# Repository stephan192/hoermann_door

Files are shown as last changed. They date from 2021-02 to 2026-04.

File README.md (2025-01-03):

# hoermann_door
Control Hörmann doors drives directly via MQTT from Home Assistant

Inspired by https://blog.bouni.de/posts/2018/hoerrmann-uap1/

**USE AT YOUR OWN RISK!**

# Overview

This repo contains the pcb files as well as the software to build an interface device which connects Hörmann door drives like the Supramatic E3 to Home Assistant. The interface device emulates an UAP1 to interact with the door drive. Additionally a BME280 can be connected via I2C to measure temperature, humidity and pressure.

<p align="center">
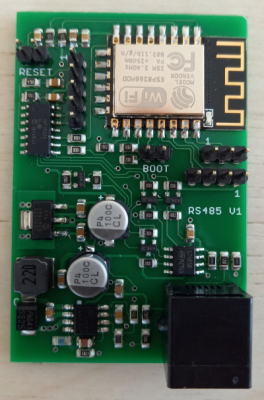
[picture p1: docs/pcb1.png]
    
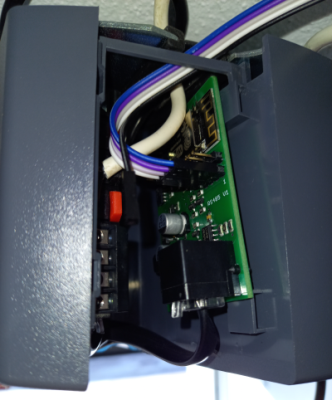
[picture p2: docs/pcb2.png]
    
</p>

The door drive is automatically added to Home Assistant via [MQTT Discovery](https://www.home-assistant.io/docs/mqtt/discovery/).

<p align="center">
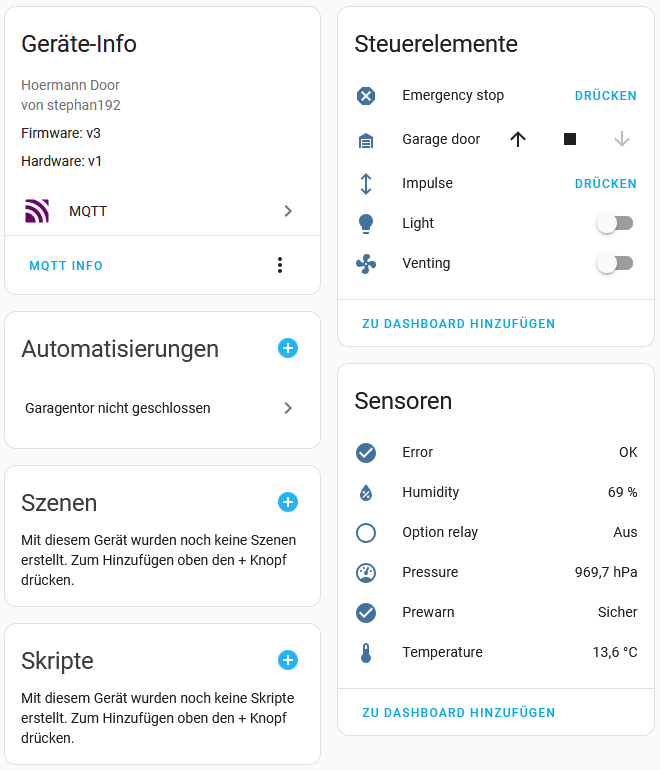
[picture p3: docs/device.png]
    
</p>

# Folder structure

* `board`: The Eagle schematic and board files
* `docs`: Documentation
* `esp8266`: Arduino project. Communication to Home Assistant via wifi and mqtt
* `pic16`: MPLabX project. Communication with door drive via Hörmann bus

# Thing to do first

1. Get a pcb
    * Optionally, get BME280 sensor pcb
    * Supply pcb with 24V via pins 2 & 3 of `J1`
    * Check if 5V and 3.3V are fine
1. Get tools listed below
1. Rename esp8266/config_template.h to esp8266/config.h and adjust to your environment
1. Add `esp8266` boards to Arduino IDE
    * Open Preferences window
    * Enter http://arduino.esp8266.com/stable/package_esp8266com_index.json into Additional Board Manager URLs field. You can add multiple URLs, separating them with commas.
    * Open Boards Manager from Tools > Board menu and find `esp8266` platform.
    * Click install button.
    * Select `NodeMCU 1.0 (ESP-12E Module)` as board
1. Add Libraries to Arduino IDE
    * Open Sketch > Include library -> Manage libraries...
    * Install `PubSubClient` (tested with version 2.8.0)
    * Install `PubSubClientTools` (tested with version 0.6.0)
    * Install `Adafruit Unified Sensor` (tested with version 1.1.4)
    * Install `Adafruit BME280 Library` (tested with version 2.1.2)
1. First flashing of `esp8266`
    * Get a cheap USB-UART converter (like the ones with a `CP210x`)
    * Connect the converter to `SV3` (RX, TX and GND)
    * Short `JP1` (Boot mode)
    * Power up board. If board was powered before reset `esp8266` by shorting `JP2`(Reset) for a short time
1. Flashing `pic16`
    * Get a Microchip programmer which supports the pic16 (PICkit3, ICD3, ...)
    * Connect the programmer to `SV1`
    * Open MPLabX and click on File -> Open Project
    * Select `pic16` subfolder (chip icon)
    * Click Clean an Build Main Project
    * Click Make and Program Device Main Project

# Used tools

## Schematic and board
* Eagle 7.2.0

## ESP8266
* Arduino IDE 1.8.13
* USB-UART converter

## PIC16
* MPLabX v5.45
* Device Family Pack PIC16F1xxxx_DFP 1.5.133
* XC8 v2.32
* PICkit3

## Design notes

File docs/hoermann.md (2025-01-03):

# Connector pinning 
1. ???
2. 24VDC
3. GND
4. ???
5. RS485, DATA-
6. RS485, DATA+

# Communication basics
* RS485 communication
* 19200Baud
* 8 databits
* No parity
* 1 Stop bit

# Typical message flow

## Startup
After Powerup the master sends the **Broadcast status** and the **Slave scan** messages alternating. The slave address used for the **Slave scan** is decremented each time a new message is send. The repeatedly used slave address range is `0x90` down to `0x10`.

## Slave detection
If a slave answers to its **Slave scan** message with **Slave scan response** the master detects the slave an starts asking the slave with **Slave status request** messages.

## Normal operation
The master sends the **Broadcast status** and the **Slave status request** messages alternating. The slave has to respond with **Slave status response**. If the slave doesn't respond the master will show error **7** and the door will not move anymore.

# Messages

## Message structure
| 0 | 1 | 2 | 3  | | length+2 | length+3 |
|---|---|---|----|-----|---|---|
| Sync break | address | counter+length | d0 | ... | dn | crc |

* `counter` are the upper 4 bits of byte 2. The slave has to answer with `cnt+1` when he received `cnt` as counter from the master.
* `length` are the lower 4 bits of byte 2. Length is the number of data bytes `d0`up to `dn`.

## CRC calculation
* 8 bit CRC
* Polynomial: `0x07`
* Initial value: `0xF3`
* The CRC is calculated over all bytes starting with the address byte and ending with the last data byte

## Known addresses
* `0x00`: Broadcast
* `0x80`: Master (door drive)
* `0x28`: UAP1

## Known commands
* `0x01`: Slave scan
* `0x20`: Slave status request
* `0x29`: Slave status response

## Known messages

### Broadcast status
Sender : Master

| 0 | 1 | 2 | 3  | 4  | 5 |
|---|---|----- |----|----|-----|
| Sync break | Broadcast addr | 0x?2 | d0 | d1 | crc |

* d0 bits:
    * `0`: door open
    * `1`: door closed
    * `2`: optional/external relay (relay 03 on UAP1)
    * `3`: light relay
    * `4`: error active
    * `5`: direction when moving (=1 closing, =0 opening)
    * `6`: door is moving
    * `7`: door is in venting position (**H** on display)
* d1 bits:
    * `0`: pre-warning active
    * `1`: ??? (seems to be always 1)
    * `2`: ???
    * `3`: ???
    * `4`: ???
    * `5`: ???
    * `6`: ???
    * `7`: ???

### Slave scan
Sender: Master

| 0 | 1 | 2 | 3 | 4 | 5 |
|---|---|----- |-----|---|-----|
| Sync break | Slave addr | 0x?2 | cmd | sender | crc |

* cmd = `0x01`: Slave scan
* sender = `0x80`: Master address

### Slave scan response
Sender: Slave

| 0 | 1 | 2 | 3 | 4 | 5 |
|---|---|----- |---|---|-----|
| Sync break | Master addr | 0x?2 | type | addr | crc |

* type = `0x14`: UAP1 type
* addr = `0x28`: UAP1 address

### Slave status request
Sender: Master

| 0 | 1 | 2 | 3 | 4 |
|---|---|----- |-----|-----|
| Sync break | Slave addr | 0x?1 | cmd | crc |

* cmd = `0x20`: Slave status request

### Slave status response
Sender: Slave

| 0 | 1 | 2 | 3 | 4  | 5  | 6 |
|---|---|----- |-----|----|----|-----|
| Sync break | Master addr | 0x?3 | cmd | d0 | d1 | crc |

* cmd = `0x29`: Slave status response
* d0 bits:
    * `0`: Trigger open door
    * `1`: Trigger close door
    * `2`: Trigger impulse (stop if door is moving, reverse direction if stopped, behaviour like the button on the remote control)
    * `3`: Toggle light relais
    * `4`: Trigger venting position
    * `5`: ???
    * `6`: ???
    * `7`: ???
* d1 bits:
    * `0`: ???
    * `1`: ???
    * `2`: ???
    * `3`: ???
    * `4`: State of pin `S0` on UAP1, i.e. the emergency cut-off button (normally `1`; if this bit is set to `0` the drive stops and error **4** is shown on the display)
    * `5`: ???
    * `6`: ???
    * `7`: ???

## Examples

### Broadcast status
| 0  | 1 | 2 | 3 | 4 | 5 |
|----|---|---|---|---|---|
| | 0x00 | 0x52 | 0x01 | 0x02 | 0xD0 |

* `0x00`: Broadcast
* `0x52`: ((0x52 & 0xF0) >> 4) = 5 = counter , (0x52 & 0x0F) = 2 = length
* `0x01`: d0, door open
* `0x02`: d1, ???
* `0xD0`: CRC

### Slave status response
| 0  | 1 | 2 | 3 | 4 | 5 | 6 |
|----|---|---|---|---|---|---|
| | 0x80 | 0x63 | 0x29 | 0x01 | 0x10 | 0x4B |

* `0x80`: Master
* `0x63`: ((0x63 & 0xF0) >> 4) = 6 = counter , (0x63 & 0x0F) = 3 = length
* `0x29`: Slave status response 
* `0x01`: d0, trigger door open
* `0x10`: d1, no emergency cut-off
* `0x4B`: CRC

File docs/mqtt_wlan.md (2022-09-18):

# Configuration
The configuration is stored in `esp8266\config.h`. If file doesn't exist copy `esp8266\config_template.h` and adopt to your needs.

# Basics
| Define | Description |
|---|---|
| `HOSTNAME` | Hostname used for WIFI, OTA and MQTT |
| `WIFI_SSID` | WIFI ssid to which the ESP should connect |
| `WIFI_PASS` | WIFI password used to connect to `WIFI_SSID` |
| `MQTT_SERVER` | IP of the MQTT server to which the ESP should connect |
| `MQTT_PORT` | Port of the MQTT server to which the ESP should connect (typically 1883) |
| `MQTT_USER` | Username used to connect to the MQTT server |
| `MQTT_PASSWORD` | Password used to connect to the MQTT server |
| `OTA_PASSWORT`  | Password used for over the air updates from Arduino IDE |
| `BME280_I2C_ADR`| I2C address of the BME280 |

# MQTT
| Define | Description |
|---|---|
| `STATE_TOPIC` | MQTT topic to which the current state of the door is published (content type: `string`, possible values: `open`, `closed`, `venting`, `opening`, `closing`, `error`, `stopped`) |
| `SET_TOPIC` | Subscribed MQTT topic to retrieve commands (content type: `string`, possible values: `OPEN`, `CLOSE`, `STOP`, `VENTING`, `TOGGLE_LIGHT`) |
| `BME280_VALUE_TOPIC` | MQTT topic to which the current value of the BME280 is published (content type: `JSON string`, example: `{ "temperature_C" : 8.24, "humidity" : 66.26, "pressure_hPa" : 986.41 }`) |
| `BME280_STATE_TOPIC` | MQTT topic to which the current state of the BME280 is published (content type: `string`, possible values: `online`, `offline`) |

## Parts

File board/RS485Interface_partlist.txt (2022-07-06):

Partlist

Exported from RS485Interface.sch at 06.07.2022 19:41:02

EAGLE Version 7.2.0 Copyright (c) 1988-2014 CadSoft

Assembly variant: 

Part     Value             Device            Package      Library                Sheet

C1       10u               C-EUC0805         C0805        rcl                    1
C2       10n               C-EUC0805         C0805        rcl                    1
C3       33p               C-EUC0805         C0805        rcl                    1
C4       100n              C-EUC0805         C0805        rcl                    1
C5       10n               C-EUC0805         C0805        rcl                    1
C6       100n              C-EUC0805         C0805        rcl                    1
C7       10u               C-EUC0805         C0805        rcl                    1
C8       100n              C-EUC0805         C0805        rcl                    1
C9       100n              C-EUC0805         C0805        rcl                    1
C10      10u               C-EUC0805         C0805        rcl                    1
C11      10u               C-EUC0805         C0805        rcl                    1
C12      100n              C-EUC0805         C0805        rcl                    1
C13      100u              UCL               UCL6.3       RS485Interface         1
C14      100u              UCL               UCL6.3       RS485Interface         1
C15      10u               C-EUC0805         C0805        rcl                    1
D1       SS25              SS25              DO-214AA     RS485Interface         1
IC1      PIC16F15324-I/SL  PIC16F15324-I/SL  SOIC14       RS485Interface         1
IC2      AOZ1283PI         AOZ1283PI         SO8+PAD      RS485Interface         1
IC3      MCP1826S-3302E/DB MCP1826S-3302E/DB SOT-223-3    RS485Interface         1
IC4      ST485BDR          ST485BDR          SOIC8        RS485Interface         1
J1       615006138421      615006138421      615006138421 InputOutputIO (rev19b) 1
JP1                        JP1E              JP1          jumper                 1
JP2                        JP1E              JP1          jumper                 1
L1       SRN6045TA-220M    SRN6045TA-220M    SRN6045TA    RS485Interface         1
R1       200k              R-EU_R0805        R0805        rcl                    1
R2       10k               R-EU_R0805        R0805        rcl                    1
R3       470R              R-EU_R0805        R0805        rcl                    1
R4       20k               R-EU_R0805        R0805        rcl                    1
R5       120R              R-EU_R0805        R0805        rcl                    1
R6       20k               R-EU_R0805        R0805        rcl                    1
R7       10k               R-EU_R0805        R0805        rcl                    1
R8       10k               R-EU_R0805        R0805        rcl                    1
R9       10k               R-EU_R0805        R0805        rcl                    1
R10      10k               R-EU_R0805        R0805        rcl                    1
R11      10k               R-EU_R0805        R0805        rcl                    1
R12      10k               R-EU_R0805        R0805        rcl                    1
R13      10k               R-EU_R0805        R0805        rcl                    1
R14      10k               R-EU_R0805        R0805        rcl                    1
R15      100R              R-EU_R0805        R0805        rcl                    1
R16      100R              R-EU_R0805        R0805        rcl                    1
R17      10k               R-EU_R0805        R0805        rcl                    1
R18      10k               R-EU_R0805        R0805        rcl                    1
R19      10k               R-EU_R0805        R0805        rcl                    1
R20      10k               R-EU_R0805        R0805        rcl                    1
R21      10k               R-EU_R0805        R0805        rcl                    1
R22      12k               R-EU_R0805        R0805        rcl                    1
R23      10k               R-EU_R0805        R0805        rcl                    1
R24      68k               R-EU_R0805        R0805        rcl                    1
R25      43k               R-EU_R0805        R0805        rcl                    1
R26      8k2               R-EU_R0805        R0805        rcl                    1
SV1                        MA05-1            MA05-1       con-lstb               1
SV2                        MA04-1            MA04-1       con-lstb               1
SV3                        MA03-1            MA03-1       con-lstb               1
T1       BSS138            BSS138            SOT-23       RS485Interface         1
T2       BSS138            BSS138            SOT-23       RS485Interface         1
T3       BSS138            BSS138            SOT-23       RS485Interface         1
T4       BSS138            BSS138            SOT-23       RS485Interface         1
U1       ESP-12F           ESP12ESMD         ESP12E-SMD   esp8266modules         1

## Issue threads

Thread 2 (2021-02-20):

PCB source

riogrande75, 2021-02-20:
I've been interrested for a while already in hoermann-hcp protocol, but this seems to be the most closest and finished project to fit my needs.
Is there a source where I can get this pcb boards?

stephan192, 2021-02-21:
Currently there is no source.
But if more people are interested i can setup one.

stephan192, 2021-03-03:
I don't know a source where to get the PCBs and i will not setup one.

stephan192, 2021-03-17:
I added gerber files to the repository but i'm not 100% sure if they are working.
I ordered my empty PCBs also at JLCPCB (without assembly) back in 2019 and i think i used the added gerber files but i'm not 100% sure.

@jmonsted if you plan to order boards can please give feedback if the gerber files are fine or not?

jmonsted, 2021-03-18:
Thanks Stephan. I found out that EasyEDA would load .sch and .brd files and already ordered that way. JLCPCB claims it's already manufactured :)
Time to source the parts...

JPM87, 2021-04-25:
Hi Stephan, thanks for sharing. I am not familiar with microcontrollers so can we replace the PIC16F15324 with PIC16F1503?

thomasdupas, 2021-04-26:
Very nice Stephan, even though I found this project way too late (I have an UAP1, with a 8266 interfaced with it on dev board; but instead of creating a PCB to do it properly I might as well use this PCB/project and eliminate the middle man)

@jmonsted since we're ~1 month further, did you succeed to source the parts? I was going over the BOM trying to match components, but not certain about some (for example SRN6045TA-, doesn't contain a value, but looking at the PCB picture it might be a SRN6045TA-220M due to the 220 print?), so I'd like to cross-reference if you're willing to share.

stephan192, 2021-04-28:
You're right L1 is a SRN6045TA-220M.
See https://github.com/stephan192/hoermann_door/blob/main/board/RS485Interface_sch.pdf

thomasdupas, 2021-04-28:
thanks for confirming @stephan192 👍,  I didn't check the pdf.
Both the sch schematics view in kicad as the pcb -> bom list showed "SRN6045TA-" (just checked again by doing a grep on a fresh checkout, to be sure it wasn't a rendering issue). Guess something got cut off perhaps at some point; I'll double check the pdf vs sch to be sure if nothing else less visible got clipped

thomasdupas, 2021-05-03:
@stephan192 I started altering the circuit/PCB, since the used DC-DC converter doesn't seem to be available at my sources. Is there an interest for a PR with this + BOM, or should I keep it in a fork?
Reason I'm asking, I'll probably add some more inputs/outputs to the esp8266 to make the same PCB usable for another motor I'm interfacing with, if there is no need for PR I don't have to split the circuit/PCB updates in to 2 stages.

And for my understanding, why did you split the code between the PIC and the ESP? Was it to have the basic "UAP" discovery etc always available even when the ESP doesn't have running code / gets reprogrammed with updates?

stephan192, 2021-05-04:
@thomasdupas I think it's better when you keep your changes in your own fork. My board is working 24/7 for 1.5years now with the selected DC-DC, so it's seems to be a good choice. Additionally my intention was to create a very minimal board without any additional features like extra IOs.

The reason why is split the code between PIC and ESP is the mainly the LIN-Syncbreak. Each message has to start with a syncbreak and i didn't find an easy solution to emit syncbreak with the ESP. Due to the fact that i'm very familar with PICs i choose to use two controllers.
@raintonr solved it with some tricks on an raspberry which also cannot emit synbreaks.
https://github.com/raintonr/hormann-hcp/issues/1
https://github.com/raintonr/hormann-hcp/issues/9

jmonsted, 2021-05-05:
I managed to get almost all of the parts from LCSC, except the SRN6045TA, PIC and SS25 that are coming from Farnell.

I filled out the BOM in EasyEDA and shared the project here: https://oshwlab.com/jesper_1127/hormann-interface

Also, i ordered five of everything, so if anyone wants a kit, i can spare a few. I'm in Denmark. I think the kit should run about €20-25 with shipping. Poke me directly if you're interested.

NemoN, 2021-05-05:
I'm interessted. I have some spare PCB too.

Abildgren, 2021-05-05:
@jmonsted, I'm in Denmark too, and is interested in two kits. Your github page does not leave details on how to contact me directly though.

thomasdupas, 2021-05-06:
my components just arrived; and PCB's are supposed to arrive tomorrow. I'm also willing to help out other people if there is a demand (located in Belgium), I have 2 spare PCB's + components for them

NemoN, 2021-05-06:
@thomasdupas I would be interested in a component set (with or without PCB - I had some made myself) Would you like to contact me via email (thomas.oeding@gmail.com)?

i5Js, 2021-05-23:
@jmonsted I’m living in The Netherlands, do you still have one?

Thanks,

thomasdupas, 2021-05-23:
@i5Js I can only provide complete boards most likely since I deviated from the original design. I currently ran out of PIC,ADM485’s and inductors; but just ordered new ones which should arrive in a week, when I could supply you with some boards.
Currently only 1 remaining completed board, which is already promised to @NemoN .
Drop me a mail if you need more information, my mailadres should be on GitHub profile page (if not, it’s <first name>@<lastname>.be

jmonsted, 2021-05-23:
I made a mistake and got the PICs in the wrong package, so i'm waiting for those to arrive (on tuesday). I have three kits up for adoption :)

I'll add my email to my github profile.

Closed 2021-07-26.

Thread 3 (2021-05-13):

Error "6." after connecting board to SupraMaticE2

riogrande75, 2021-05-13:
I recently built this project and I am pretty confident, that everything was soldered together and programmed correctly.
Right now, a UAP1 and a button is connected to my SupraMaticE2 - this works so far.
As soon as I replace the UAP1 with the board from this project, I get following output on my MQTT server:
```
[2021-05-11 16:39:46.695584] garage_links/cover/state stopped
[2021-05-11 16:39:46.695644] garage_links/sensor/garage/status offline
```
Unfortunately it does not respony to any of my issued commands:
```
[2021-05-11 16:41:12.825838] garage_links/sensor/garage/set CLOSE
[2021-05-11 16:41:18.133533] garage_links/sensor/garage/set TOGGLE
[2021-05-11 16:41:59.022011] garage_links/sensor/garage/set OPEN
[2021-05-11 16:42:01.973374] garage_links/sensor/garage/set OPEN

```
If I want to open close the door manually with the button, I just get fault "6." in the display.
This points to a fault on the / open "Schlupftür". But I do not have a "Schlupftür" installed at all and the RJ25 plug with the shorting wire in X30 is placed correctly.
As soon as I put UAP1 back in place everything works fine again.
Connecting RPi with RS485 and running [https://github.com/raintonr/hormann-hcp](url) works too, so I guess the door and control unit are ok.

Any idea from the specialists on how I could debug here?

stephan192, 2021-05-15:
My guess:
A wrong, missing or twisted part is messing up the hoermann bus.

To narrow down the problem:
1. The manual for my Supramatic E3 says error 6 means "Systemfehler" (system error) which would make more sense.
2. When you have disconneted all slaves (UAP1, this board, raintor's interface) the drive shows error "7". Right?
3. `garage_links/cover/state stopped` is the default state if no communication with the drive could have been achived.
4. `garage_links/sensor/garage/status` offline is the default state if no BME is connected.

The next steps i would perform:
1. Check the board's supply voltages. Are 24V, 5V and 3.3V fine?
1. Check the RS485 lines with an oscilloscope. Can you see the master messages or is it just a flat line?
2. Check the board parts on the RS485 side (IC4, T1, T2, T3, T4 + surrounding parts). My guess is that one or more parts have wrong values or are mounted twisted.

riogrande75, 2021-12-09:
Ok, finally found time to work on this issue again. Factory resetting my SupraMatic E2 solved the error 6 problem easily.
BUT: I dunno why I was reading over it so many times: This project is for Supramatic**E3** and not my E2 - so it will not work anyway. :-(

Closed 2021-07-26.

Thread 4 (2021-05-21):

Toggle lights

snoekieboe, 2021-05-21:
Hi Stephan, First of all thanks for all your nice work. I've managed to get my hand on a PCB made according to your design and it is working like charm.

I've noticed the presence of a toggle light option in the Pic16 code and was wondering if it is already possible to use this feature through MQTT... could not verify this to be true whilst looking through the esp8266 code.

Thanks in advance !

stephan192, 2021-05-22:
Hi snoekieboe,
as i analyzed the bus i found out that one bit toggles the light, so i implemented it in the pic16 software to document it. But i didn't find a meaningful usecase for this feature so i didn't add it to the esp software.

If you need it you can easily activate it by adding the following lines after line 241 to esp8266.ino
```
if (message == "TOOGLE_LIGHT")
{
  door.trigger_action(hoermann_action_toggle_light);
}
```

And publish a message with payload `TOOGLE_LIGHT` to your `SET_TOPIC`.

snoekieboe, 2021-05-22:
Thnx Stephan! I will add the code  and see if it works. Keep you posted!

stephan192, 2021-06-18:
I've added the feature but do not recommed to use it due to a missing feedback.

i5Js, 2021-07-25:
It's working; sending the payload(on/off) "LIGHT" turn on and off the light, but in HA, I don't know how to do correctly a switch like "Venting". I think It's because the value is always LIGHT.

stephan192, 2021-07-26:
You must configure your switch to work in optimistic mode (don't define a state_topic) and that's exactly the thing why i don't recommend using toogle light.

stephan192, 2021-07-26:
The complete solution would be:
1. Verify which bit of the broadcast status message is the light relais
2. Add an interface function to hoermann.cpp
3. Convert the cover position topic to a json message to be able to add more than one value
4. Adjust the configuration.yaml or additionally add [MQTT Discovery](https://www.home-assistant.io/docs/mqtt/discovery/)

**But i will not do this, at least in short term. Feel free to make a pull request.**

Closed 2021-06-18.

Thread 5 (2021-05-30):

Promatic 4 - Bus scan fails

snoekieboe, 2021-05-30:
Hi Stephan,

Sorry for bothering you but i've managed to source the PCB you designed and flashed both the ESP8266 and the PIC16 with your code to get it up and running in combination with my Hormann Promatic 4 door.

When i connect the PCD to the Hormann BUS:

* Initially nothing happens
* After toggling dip switch 8 (bus scan):
* The PCB is powered
* ESP8266 connects to the network (can ping the device)
* Lights on door start flahsing red/green rapidly (is supposed to happen on bus scan)
* As soon as bus scan finishes PCB loses power

Seems to my like the PCB is not recognized by the bus scan hence powering down the bus.

What could go wrong..?

* is the code not detecting the door?
* Is my PIC16 not flash succesfully?
* Something else?

any suggestions to point me in the right direction would be much appreciated

Thnx!

thomasdupas, 2021-05-30:
a promatic 4 has a different protocol (it's using plain modbus from what I understood), so that won't work with this variant for now.
I'm going to a friend in ~1 week to measure it with a scope/logic analyser, since it would be good to be able to do both variants of the protocol with the same device (with a different cable perhaps, depends on the pinout).
If successful I'll make a variant of the code which can do both, you can always contact me if you want follow-up on situation

snoekieboe, 2021-05-30:
Aaah that explains a lot!  I will keep in touch for sure! Thnx!

spacemanspiff2007, 2021-05-31:
@thomasdupas
I am searching for a new garage door motor and haven't made up my mind yet.
It would be really nice if you could make your findings publicly available.

stephan192, 2021-05-31:
After a quick search i figured out that Hörmann offers an adapter called HAP1 HCP which makes it possible to connect old accessories (like the UAP1 which the PIC emulates) to new doors (like Promatic 4).
The old accessories are using version 1 of the HCP protocol whereas the new doors are using version 2 which isnt' compatible to version 1.
I found the following compatibility list: https://cdn.hoermann-cloud.de/fileadmin/_country/kataloge/pdf/hcp_kompatibilitaet.pdf

thomasdupas, 2021-06-04:
"progress", google revealed that someone already did some sniffing and has a working solution
https://github.com/hkiam/HCPBridge/blob/master/Investigation/ProtocolAnalyse.txt

What I find strange though, it wouldn't send distinct target states anymore, but more "button emulation"
for example:
0015: 02 17 10 70 00 03 01 02 10 00 00 00 00 00 00 00 00 00 00 6C 88 		&lt;- Tor auf pressed
0015: 02 17 10 78 00 03 01 01 10 00 00 00 00 00 00 00 00 00 00 6F 4A 		&lt;- Tor auf released

0015: 02 17 10 6C 00 03 01 02 20 00 00 00 00 00 00 00 00 00 00 9B 41        &lt;- Tor zu pressed
0015: 02 17 10 78 00 03 01 01 20 00 00 00 00 00 00 00 00 00 00 90 4A 		&lt;- Tor zu released

Sounds a bit odd to me why they wouldn't use the distinct states in the protocol for something like the UAP

pboschi, 2023-01-07:
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

Hi, did you ever finish the adaptation for ProMatic 4 series? Thanks

Closed 2021-07-26.

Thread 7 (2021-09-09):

Almost working with my SupraMatic E2

lg2dc, 2021-09-09:
Hi Stephan,

Firstly, thanks for your work and your sharing. I discovered that it was possible to draw boards ourself and even ask to build of a small amount of boards from manufacturers or web sites. (Even if I still have to learn a lot before being able to draw a working circuit myself :-D )

I got a board from a participant to [your HA Community Forum thread](https://community.home-assistant.io/t/hormann-garage-door-via-mqtt/279938).
My garage door is a SupraMatic E2, as far as I can understand from the Article Number on the motor box.

The participant was very kind to flash the PIC for me because I don't have any Microchip programmer.
And I flashed the ESP myself.

I can trigger commands: open, close, venting and toggle lights.
But _**the state is not reported**_, I always get "stopped" in the MQTT topic.

(The buttons on the motor box, the wall and remotes are still working as before, I do not have the error 6 like in the issue #3, but I don't have any UAP1 currently)

I'm quite newbie in hardware development and my first tests are with ESP32 dev boards using the [esphome.io project](https://esphome.io/).
So, to investigate the problem a bit deeper, I moved your code to an esphome project. I had to use a "custom component" as this implementation is not common off course. I succeed to reproduce the same behaviour: sending commands but no state reports.

I added some logs, especially inside the "parse_input" function, and discovered that the PIC is communicating with the ESP but it always reports 0 in the "state byte".

Here are the logs:
```
[12:32:52][D][garage:223]: parse_input rx_buffer[0] = 85
[12:32:52][D][garage:224]: parse_input rx_buffer[1] = 0
[12:32:52][D][garage:225]: parse_input rx_buffer[2] = 2
[12:32:52][D][garage:226]: parse_input rx_buffer[3] = 0
[12:32:52][D][garage:227]: parse_input rx_buffer[4] = 0
[12:32:52][D][garage:228]: parse_input rx_buffer[5] = 87
[12:32:52][D][garage:229]: parse_input rx_buffer[6] = 0
[12:32:52][D][garage:236]: parse_input 3 = 0
[12:32:57][D][garage:223]: parse_input rx_buffer[0] = 85
[12:32:57][D][garage:224]: parse_input rx_buffer[1] = 0
[12:32:57][D][garage:225]: parse_input rx_buffer[2] = 2
[12:32:57][D][garage:226]: parse_input rx_buffer[3] = 0
[12:32:57][D][garage:227]: parse_input rx_buffer[4] = 0
[12:32:57][D][garage:228]: parse_input rx_buffer[5] = 87
[12:32:57][D][garage:229]: parse_input rx_buffer[6] = 0
[12:32:57][D][garage:236]: parse_input 3 = 0
```

Do you have an idea of what could be problematic ?
Or where I should investigate more ?

I guess that the problem will be in the PIC code, but I wanted to confirm before going further.

I can share my esphome project code if it can help. I was planning to share it when it was ready.

Thanks in advance for your help!

stephan192, 2021-09-09:
Hi @lg2dc ,
i don't think there is a problem in the PIC code. You door is an E2 mine an E3. Maybe your door doesn't report back any status.
The door state (rx_buffer[3] & rx_buffer[4]) are 1:1 the original bytes received from the door drive. So i think you door always reports them as 0.

To dig deeper into the problem i recommend that you get yourself a RS485 USB dongle an log the messages on the hoermann bus the see what the door drive reports in the Broadcast status message.

lg2dc, 2021-09-13:
Hi @stephan192,
Thanks for your reply.

Right, there is a difference in the model. And that's why I was thinking that something should be adapted in the PIC code, like an "address" byte maybe.

If I well followed the code, the esp interface is continuously sending the content of the [broadcast_status](https://github.com/stephan192/hoermann_door/blob/0465f8ea44073dfaa37781686e3fe92cc14d4c3b/pic16/hoermann.c#L58) variable which is initialized to 0. Even if there is no change, right?

If I'm right, there is 2 possible cases:
1) the variable is never updated because the [broadcast message is not received or filtered](https://github.com/stephan192/hoermann_door/blob/0465f8ea44073dfaa37781686e3fe92cc14d4c3b/pic16/hoermann.c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)
2) the variable is updated with 0 contained in the broadcast message

So you are right, I should investigate what my drive is sending. Initially I was thinking to update the pic code to forward everything to the esp and log it, but there is maybe a better solution. Like listening directly the bus, as you suggested.

Do you think that the door drive will broadcast even if no UAP will be connected to the bus? Or should I connect in parallel the USB dongle and your board to the bus (I don't know if it's allowed for RS485)?

stephan192, 2021-09-13:
> If I well followed the code, the esp interface is continuously sending the content of the broadcast_status variable which is initialized to 0. Even if there is no change, right?

Yes, that's right.

> If I'm right, there is 2 possible cases:

My guess is **case 2**: Variable is updated with 0.

> Do you think that the door drive will broadcast even if no UAP will be connected to the bus? Or should I connect in parallel the USB dongle and your board to the bus (I don't know if it's allowed for RS485)?

You can (better to say must) connect the USB dongle in parallel. If you remove my board your door will not function anymore and report an error.
See https://community.home-assistant.io/t/hormann-garage-door-via-mqtt/279938/26

riogrande75, 2021-12-10:
@lg2dc Did you succeed creating a pic firmware working with your Supramatic E2?
I just noticed that the project was made for a E3 and I own two E2's. Got it working with raintonr's project, but it's unstable and I would prefer the hardware from this project.
I even bought a defective E2 motor drive, repaired it and use it now for testing - its much warmer in my lab than in the garage.
Pls. let me know if I can contribute something for your investigations.

fox34, 2025-02-17:
Some background: The broadcast from a Supramatic E2 seems to differ from E3. It's just 1 byte of payload (uint8_t) instead of 2 (example: `00 01 01 C3`), which signals one of:
- Door fully closed (`0x02`)
- Door fully open (`0x01`)
- Door neither open nor closed (`0x00`)

There is no information about movement, light, error states etc. as in newer models. The code would need to be updated to also accept broadcasts with 1 byte (and to not provide and rely on incorrect/missing state information).

One other significant difference: The impulse command does not stop a moving door, emergency stop (signalling an error) must be used.

Closed 2022-07-06.

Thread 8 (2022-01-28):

AOZ1038PI safe to work with 24V input?

mmanchev, 2022-01-28:
Hello, your project is great and it's exactlhy what I needed for my Hormann doors. I'm trying to reproduce the board, and while browsing for parts, I've noticed that datasheet for AOZ1038PI says "4.5 V to 18 V operating input voltage range". As per the schematic, the input voltage is 24V. Is it safe to operate in that range? Also the 10u C0805 capacitors should be at least 25V I suppose?

Looking forward for your reply.

Regards

stephan192, 2022-01-29:
Hi, it seems as if you have a twister in the part number. **The AOZ1038PI is not suitable**. The schematics contains the **AOZ1283PI** which is designed to operate up to 36V.
For C1 (the 10µF capacitor at the input) 25V is the absolute minimum rated voltage. If you have a closer look at datasheets for the different ceramic materials C1 should better have a rated voltage of 50V.

mmanchev, 2022-01-31:
Аhh, you are right. I used online gerber tool to generate me BOM with links to the componets, and probably because of stock shortage it linked to the wrong version. Thanks for that. I'm struggling to get all the components, but I will manage it soon or later. We can close this issue.

Closed 2022-01-31.

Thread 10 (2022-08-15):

Can I Substitute the  PIC16 for a different PIC16?

Gamogamer, 2022-08-15:
The chip you use in the design is basically sold out in all normal shops and I was wondering if I could Replace the
PIC16F15324-I/SL
with the
PIC16F15325-I/SL

Looking at the Datasheet
https://ww1.microchip.com/downloads/en/DeviceDoc/PIC16F-LF-1532444-Data-Sheet-DS40001889C.pdf
(from https://www.digikey.de/de/products/detail/microchip-technology/PIC16F15324-I-SL/6691276)
it seems the only difference is bigger memory. (Not that I really know what I am looking at otherwise)

I also had to redo the power circuitry for similar reasons and ill upload that in a fork or something once i figure out how to actually use github and that it works.

stephan192, 2022-08-16:
After a quick review of the datasheets i think (no guarantee) it should easily be possible to switch from the PIC16F15324-I/SL to the PIC16F15325-I/SL.
My conclusion is the same as yours. Both have the same peripherals, the only difference is that the 25's flash and RAM size is double compared to the 24. The most important thing to mention is that the PIC needs to have two UART modules.

But after a quick search i don't think it's easier to get the PIC16F15325-I/SL quicker than the PIC16F15324-I/SL.
In your place is would first try if i can get the same chip in a different housing or with a different temperature rating.
Mouser for example has currently some PICs in DIP package (PIC16F15324-I/P) on stock.
Have a look a page 556 (PRODUCT IDENTIFICATION SYSTEM) of the document you mentioned.

LocalNic, 2022-12-03:
> So as it turns out I overlooked that this is for Supramatic 3 and i have the 2. While my new design seems to work programmingwise and so on, I can't actually test it on a Supramatic 3. Bummer. If anyone wants the PCBs I am not looking to figure out a way to make them work with my V2s, nor do i have the equipment. I can also provide the schematics and so on if wished for.

Hi Gameogamer, I have two Supramatic 3 and I'm looking for a way to connect my DoorMotors with MQTT or something like that. but I am not so firm in programming the PIC. I have experience with the ESP anyway.

If you still have the PCBs around leae me a line to 127.0.0.1@web.de

Gamogamer, 2022-12-12:
I wasn't able to send you an EMail, I get an error EMail not found

kom3n, 2022-12-13:
If still available, I am also insterested. Contact: borrob07@gmail.com

LocalNic, 2023-01-25:
Sorry I just received the notification by GitHub. Is misses a number
127.0.0.11@web.de

Closed 2023-01-25.

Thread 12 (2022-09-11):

Boards for sale

riogrande75, 2022-09-11:
I built 2 of these beauties with the boards from stephan192, before I noticed, that they don't work with my SupraMatic E2 doors.
Boards are fully assembled, FW is flashed, tested, so you just have to flash ESP32 with your settings again and you are good to go.
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

Jarda-cz, 2022-09-11:
Hello,
  I'm interested, if you have one left.

Abildgren, 2022-09-11:
Im also interested if there is one left.

riogrande75, 2022-09-12:
Ok, pls. send me your email adresses - I will contact you.

Jarda-cz, 2022-09-12:
My email is jarda.moravec@gmail.com . Thank you!

Abildgren, 2022-09-12:
> Ok, pls. send me your email adresses - I will contact you.

Github (a) Abildgren (.) dk

johnreitan, 2022-11-02:
Any chance you could build a few more?

LocalNic, 2022-12-03:
I am also interrested .. I also like to oder them directly from jlbpcb. but for that I might need a short documentation which files I need to have the PCB right, the parts and their placement I guess.

Or like my precessors, just buy it from some talented Maker. ;)
br

MatthiasLohr, 2023-01-07:
> Any chance you could build a few more?

Same question from my side... Any chance?

wallo66, 2023-11-23:
I´m also interrested to buy a board, ist it possible?

threadstone83, 2024-02-07:
Me too. It would be nice if they could be bought.

realdimik, 2024-04-20:
I have 3 extra for sale. If someone is still interesting, send me your email for contact.
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

MatthiasLohr, 2024-04-20:
I'm interested, will write you an email shortly.

johnreitan, 2024-04-20:
I'm too, will email too shortly

MatthiasLohr, 2024-04-20:
Can't find your email address anywhere. In case you wanted our mail addresses instead: mine is mail@mlohr.com, would be great if you could contact me. Thanks!

realdimik, 2024-04-22:
Now all 3 are sold out.

Closed 2022-09-13.

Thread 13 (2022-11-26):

Parts substitution & JLCPCB ordering

pboschi, 2022-11-26:
I was trying to produce a JLCPCB order list (see attachment), but the following parts are missing and very difficult to find. Are you able to suggest alternatives, or to modify the gerber with some more common ones?

The following should be ok:

- MCP1826S-3302E/DB ==> SPX3940AM3-L-3-3/TR
- ST485BDR ==> ST485EBDR
- ESP-12eSMD ==> ESP-12F(ESP8266MOD)
- 100u ==> RVT100UF16V67RV0120

But I'm having issues with the following:

- AOZ1283PI
Can't be found.

- **SRN6045TA-220M** ==> **VLS6045EX-221M** or **VLS6045EX-220M**
Lower max current, but is it needed? Also, i think this is a mistake; shouldn't the inductor be 22uH, reading on AOZ1283PI datasheet? So maybe VLS6045EX-220M is a better choice.

- **PIC16F15324-I/SL** ==> ?
Candidates are:
PIC16F15325-I/SL but it can't be found
PIC16F18326-I/SL but it doesn't have 2 EUSART

I'm really not an electronic engineer and I don't have the skill to change the PCB, but I think that the buck regolator and PIC really need to be changed with more common ones.

[RS485Interface_top_cpl.csv](https://github.com/stephan192/hoermann_door/files/10096052/RS485Interface_top_cpl.csv)
[RS485Interface_top_bom.csv](https://github.com/stephan192/hoermann_door/files/10096053/RS485Interface_top_bom.csv)

pboschi, 2022-11-26:
I did some further checks, and those parts are available in other parts of the world... so I think I'll order from JLCPCB and just solder the missing parts by myself.
However, I still have a doubt about the 220/22uH inductor.

stephan192, 2022-11-26:
The inductor SRN6045TA-220M is a 22uH inductor.
See [Datasheet](https://www.bourns.com/docs/Product-Datasheets/SRN6045TA.pdf)

stephan192, 2022-11-26:
When i started this project back in 2019, all the parts were easily to source.
Sorry, but i will not update the gerber files (change parts or suggest alternatives) if i don't need it myself because the chip market is changing nearly every day and a part which is available today maybe sold out toworrow.

Closed 2023-01-17.

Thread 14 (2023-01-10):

ProMatic 4 BiSecur 4510293

espuno, 2023-01-10:
does it also work with the Hörmann ProMatic 4 BiSecur 4510293 garage door opener?

Abildgren, 2023-01-10:
AFAIK Only with the HAP1 HCP adaptor https://www.tor7.de/hoermann-adapterplatine-hap-1-hcp as they have changed the protocol

stephan192, 2023-01-10:
The board only supports version 3 drives yours is a version 4 drive.
Check the lastest comments in [home assistant forum](https://community.home-assistant.io/t/hormann-garage-door-via-mqtt/279938/88) and [Thomas Dupas’s blog](https://blog.dupas.be/posts/hoermann-uap-hcp1/)

thomasdupas, 2023-01-11:
Hi, let me chime in here since it comes up often, since I'm indeed the author of above blog article (which has a blatant typo in the title/url, first time I notice it myself ;-)).

My intent/contribution at the time was to disclose the inner workings, as @Bouni had done at the time; where @stephan192 based his marvellous work here on, I myself build further on his work for own usage; and shared the research of E4 to the community. Thus coming full circle again, at least that was the intent.

I hope many people found the protocol information useful, that was my intent at the time. The focus seems to be on the finished product I have the impression, early on I got requests if I was willing to sell/ship readymade PCB's.
Since I had some spare PCB's for the minimal order (and to make the passive component picking/shipping price not greater than the passives) I indulged and shipped a few. I didn't anticipate the consequences this would have depending on the audience. It ends up at people with zero knowledge about homeassistent, mqtt, FTDI adapter, programming a microcontroller, … Some seem to expect help and aftercare/support on those items.
One bad experience in that area where I spent a considerable amount babysitting left a bad sentiment and made me abandon it.

Setting up something with that intent also has different requirements, both regarding to UX (buttons, visual feedback), as hardware (on-board FTDI chip, usb port, …), as documentation surrounding it; that becomes a commercial undertaking. On the homekit version some of those aspects are solved, less external dependencies, but if it’s not for own usage you have different license and compliance requirements from apple before you’re able to distribute it.
And on the other hand with the current supply chain it’s hard to make a static design and do small batches. You have to modify your BOM/design depending on the current stock, which will very likely be different if you do it again a month in the future.

So apologies for all the people who emailed me and didn’t get a reply, I literally made an email filter to park all those emails in a separate folder with the intent to go through them in due time, there are way over 100 requests in that folder I see now. I had a hardware redesign in progress at the time which I abandoned due to above reasons, the road to hell is paved with good intentions ;-).
But if it gets published it will come with a clear minimum expected self-sufficiency statement to avoid the same pitfall.

espuno, 2023-01-11:
People think your work is great @thomasdupas
https://github.com/hkiam/HCPBridge/issues/13

Your PCB could you possibly make public?

TUNER88, 2023-01-11:
Hey @thomasdupas 👋

It is really sad to hear that you have faced that bad experience. It is also fully understandable that you are unable to do any kind of support that was (for some reason) expected after shipping.

Would be cool if you could open source the PCB design files and the source code. The community seems to be quite big, I can imagine that we can find somebody who is able to update your BOM/design so we can order it ourselfs.
I do not have any selfmade PCB expirience yet, but would like to give it a try. There seems to be services that even do the assembly for you: https://www.pcbway.com/pcb-assembly.html

i5Js, 2023-01-24:
Hey @thomasdupas  I have just seen your post. Now I understand why I didn’t get any news from you. I sent you an email even today, because I flashed OTA the latest changes from this GitHub and now I can’t connect anymore with the board. I have tried to disconnect from my wifi to get the recovery mode, but It didn’t work either. I you could help me how to move on I would really appreciate.

Anyway, thanks for your time you spent with me two years ago.

Take care

Best

Closed 2023-01-10.

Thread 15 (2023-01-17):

Garage door is "read only" using HMIP HAP1-HCP adapter on Promatic4...

pboschi, 2023-01-17:
Hi, as suggested by you in https://github.com/stephan192/hoermann_door/issues/5#issuecomment-851629119 and @Abildgren in https://github.com/stephan192/hoermann_door/issues/14#issuecomment-1377003619, I tried the HMIP HAP1-HCP adapter to connect your device to a Promatic 4 motor.

Issues so far:
1) I had to "jump start" the device powering it from +24v accessories plug of the motor and not from the bus. There is no power on the bus of Promatic 4 motors until you start a bus scan. So (i think) the scan fails because the ESP32 isn't quick enough to boot, and so the HMIP HAP1-HCP adapter turns off and so does the ESP32. When the PCB is powered externally, the scan succeeds, and from this point on the bus remains powered, and the adapter HAP1-HCP remains always on (even you disconnect the PCB). Would have been nice to have a separate power in pin terminals on the PCB... And also the blue led, it turns on only for an istant when you give power, would have been nice to have it on permanently when device is powered. Anyway, once "jump started", it will work as-is (until maybe you reset the bus?).

2) The MQTT commands to open/close and turn on/off light do not work. The status report is OK and aligned with the real status of the door (e.g., if I open the door via remote, I see it on MQTT; but if I try to open it via MQTT, it doesn't work).

It's like the motor is "read only"...

Do you have any suggestion?

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

stephan192, 2023-01-21:
I don't have any clue why it doesn't work. There can be a lot of reasons. My first guess would be timing issues between the board and the HAP1-HCP.
To dig deeper into to problem i would start with connecting an original UAP1 to test if an 100% Hoermann setup is working.

Due to the fact that i neither own a version 4 drive, nor an HAP1-HCP nor an UAP1 i can't really help you with this.

Closed 2023-05-01.

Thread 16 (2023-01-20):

Can you please upload PCB assembly related files too?

halacs, 2023-01-20:
Hi,

I would like to order this PCB from seedstudio.com in an assembled form. I need to upload assembly instructions and BOM files.

Can you please help me out with these?

I attach a screenshot about a web form I face with. Sorry for the dumb request. :)

Thanks!

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

stephan192, 2023-01-21:
First of all: I assembled my board manually so the fabrication data is not 100% ready.

- I've added the pick&place file.
- The BOM is already in the repo ([partlist](https://github.com/stephan192/hoermann_door/blob/main/board/RS485Interface_partlist.txt)), but you must adjust it to seedstudio's requirements. Expecially the BOM doesn't contain "exact" part numbers. E.g. 10k 0805 is a generic 10k resistor in 0805 package which must be linked to an existing part. The pin headers (JP1, JP2, SV1, SV2, SV3) don't have values because i've just cut them of a longer pin header. When selecting expecially capacitors be careful with the rated voltage.
- I don't have any testplan, visual inspection is enough.

Closed 2023-05-01.

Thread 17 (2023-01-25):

Unable to flash OTA

i5Js, 2023-01-25:
Hi all,

I had my board flashed and working fine with my E4 door. I saw there were changes and I decided to flash the board OTA, like always. I made a mistake with the config.h and now the board doesn’t work, but, I can either find the way to reflash it OTA, all the ports are close now.  I guess I will need to solder the pins to have the serial working, but, what I did wrong? I remember, when I had this issues before, the board can enter in a recovery mode if it doesn’t detect the wifi, but not anymore… Any advice?

Thanks,

stephan192, 2023-01-25:
Hi @i5Js,
are you sure you got it working with an **E4**? If really you would be the first one ever. See #15
Which recovery mode, I don't know any recovery mode? If OTA isn't working you have to flash it via serial port.
Are you sure you opend your issue in the right Github project?

i5Js, 2023-01-25:
Ok, now all make sense. Thomas code and this code is different. His firmware had a recovery mode, and indeed, it worked in my E4. I will solder the serial port and will put his firmware back.

Thanks

Enviado desde dispositivo móvil
________________________________
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

Closed 2023-01-25.

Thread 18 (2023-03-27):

Compatibility with Lineamatic gate motors?

fodi666, 2023-03-27:
Hi,
I've just stumbled upon this project. I have a Lineamatic 2 gate motor that I'd like to add to Home Assistant. Is this project compatible with this motor? I think it is a Series 3 motor, but I'm not sure. Can I use the "venting" option for the "small gate" option (partial open)? Does it also report open-close-opening-closing-partially open state?
Thanks

fodi666, 2023-03-27:
I've found a pdf somewhere about the compatibility of the HCP module where it said Series 3:
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
(unfortunately it's in Hungarian, but "3-as sorozat" means "series 3")
The module's manual also states the UAP1 or the UAP1-300 as a compatible addon board. Can it be used in this case then?

stephan192, 2023-03-27:
I can't say, because I don't have one. You have to try it yourself.

fodi666, 2023-04-03:
Thanks, I'll try. One more question: can the PIC and the ESP be programmed on board, or do they need to be programmed before soldering them? If they can be programmed on board I could order the board presoldered from China and it would make my job a lot easier. If not, then I'll have to leave at least the PIC and the ESP unsoldered.

stephan192, 2023-04-04:
They can both be programmed "on board".
To program the PIC connect a supported microchip programming tool to SV1.
To programm the esp connect a USB-UART converter to SV3 and enter "programming mode" like described in the README.md

kovlo, 2024-01-17:
> Thanks, I'll try. One more question: can the PIC and the ESP be programmed on board, or do they need to be programmed before soldering them? If they can be programmed on board I could order the board presoldered from China and it would make my job a lot easier. If not, then I'll have to leave at least the PIC and the ESP unsoldered.

Did you manage to try this on Lineamatic? I'd be interested in it as well. Were you able to order the board assembled and even preprogrammed? If yes, please share the source with me.

fodi666, 2024-02-26:
@kovlo no time so far, sorry

realdimik, 2024-04-21:
I have Lineamatic and yesterday I've connected a board to it.
It correctly reports status of the gate, even "option relay", but It can't send any command :(
I found that people had the same symptoms when they tried to use it with E4 ( https://community.home-assistant.io/t/hormann-garage-door-via-mqtt/279938/95 ). But I didn't change the pins, so it should be compatible with UAP 1, not with E4 series. I have currently no idea what to do next.

realdimik, 2024-05-03:
I've reviewed the code of Stephan and debugged it with Lineamatic. I've got that master (Lineamatic by itself) doesn't not send slave status requests.
After googling about the problem I found it in https://github.com/raintonr/hormann-hcp/issues/1
In that issue Stephan by himself gave an advise to Robin regarding the problem reason

> Every message on the bus must start with a sync break (according to the LIN standard). A sync break are at least 13bits low, this is not the same as sending one or two zeros (each of them is only 8bits low). As the name says a sync break breaks the "normal" protocol frame to trigger an error = resync in every connected device.

I've reviewed code JS code of Robin and found that he followed the advice and solved the problem by switching boudrate=9600 and databits=7 temporary for sending the syncbreak.

Robin also mentioned that in the answer to Stephan:
> In fact, this can be achieved by setting the baud rate down to 9600, data bits to 7 then sending a zero, which in effect holds the transmit line high for long enough. Remembering to turn communications parameters back to normal before continuing.

I also found the same solution in one more repository https://github.com/steff393/hgdo/blob/master/src/uap.cpp#L209

But in the code of Stephan there is no such switching, just
>/* Start with a Syncbreak */
  tx_counter = 0;
  TX1STAbits.SENDB = 1;
  TX1REG = 0x00;

Unfortunately I have no experience with programming PIC controllers. By reading the code and documentation I've got how to change bound rate, but I have no idea how to change data bits. It would be great if someone experienced (or @stephan192 by himself) can help me with that.

stephan192, 2024-05-05:
Hi @realdimik,

my software for the PIC issues a LIN conform syncbreak. The implementation of Robin for examle is just a workaround which seems to be working but is not what the standard requests.

For the PIC you found the right piece of code where the syncbreak is generated. It are just three lines of code. Please have a look at the [datasheet (page 438 chapter 33.3.4)](https://ww1.microchip.com/downloads/aemDocuments/documents/OTH/ProductDocuments/DataSheets/PIC16F-LF-1532444-Data-Sheet-DS40001889C.pdf) for more details.

`/* Start with a Syncbreak */`
`tx_counter = 0;`
`TX1STAbits.SENDB = 1;`
`TX1REG = 0x00;`

**In conclusion: There is no need for baudrate change within my software!**

If the Lineamatic doesn't sent slave status requests i currently don't see any change to control the door via my board.

realdimik, 2024-05-05:
Hi Stephan,

thank you for the reply. It is clear.
My assumption was made based on that Robin got Lineamatic work, and I only needed to find the difference in approaches. But finally I found not a difference, but my misunderstanding of PIC registers that you've described.

I will try to research a bit more. I will try to simulate Lineamatic by PIC and connect it to Hormann ese-868-bs that I have, and log how slave scan reply looks like.

In case of not success, I have plan B: connect a toggle gate button in Lineamatic board to an ESP.

For logging currently I'm collecting all messages in long memory buffer and make a breakpoint when it full to grab it using watches in MPLab. Does more standard way for logging exist?

rgds,
Dmitry

realdimik, 2024-05-05:
I've simulated Lineamatic by PIC and got from ese-868-bs a slave scan reply similar to UAP1, but with addr=0x29 and type=0x10 (makes sense). I've also measured timing. ese-868-bs replies by 9ms, not 3ms.
Then I sent the same slave scan reply using PIC to Lineamatic, but didn't get any slave status request with any timing from 3ms to 12ms :(

stephan192, 2024-05-05:
What do you mean by
> I've simulated Lineamatic by PIC

The Lineamatic is the Master and the PIC or the ESE is the slave.

The "response delay" (3ms in my case) would be the next value i would start playing around, but you already did that. As far is a can remember is started with 0ms and my E3 didn't accept my slave can reply with 0ms delay.

My guess is that the Lineamatic doesn't accept/receive the slave scan reply by any reason. Normally the master keeps on sending the slave scan message until he receives a vaild reply. But, as far as i can remember, if it once has found a slave it never sends the slave scan again until the drive is reset.

I would do the following things as next steps:
1. Connect an additional rs485 dongle to the bus and log the messages on a PC.
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
realdimik, 2025-01-11:
There is no equivalent for R5 in ese-868-bs. They have nothing at all.

stephan192, 2025-01-11:
That's very interesting.

R4 and R6 are so called bias resistors which should keep lines A and B in a valid range if no device is driving the bus. If the door drive itself already has them included and your lines are short enough removing them shouldn't be a problem. I don't remember why i choosed 20k a value. Maybe because it is way more then typically used on RS485 and so it shouldn't be a problem having them in parallel to possibly existing bias resistors inside the drive.

R5 is, as 14yannick already said, the termination resistor which should be placed, according to the specs, at both ends of the line. If the lines are short it may work with just one resistor. Has someone every measured the resistance between A and B of the door drive when everything is powerless and nothing is connected? Maybe the door drive has just 60Ohms build-in as termination between A und B. This could explain why you didn't find a termination resistor in the ese-868-bs.

djasper-ha, 2025-01-11:
> Regarding you working board. The firmware has an autocorrect [function](https://github.com/14yannick/hoermann_door/blob/a15263402a5daeb43a0997aa02d5123089e884fa/esphome/components/uapbridge_esp/uapbridge_esp.cpp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). Could you check in your log if it's offen triggered.

I don't see it triggered at all.

djasper-ha, 2025-01-11:
I also removed R4 and R6 and it didn't solve the problems I am seeing. The LineaMatic still stops after 1-3s showing error code 4.

14yannick, 2025-01-11:
Do you have some 4.7k Ohm resistor laying around you can put at R4 and R6. This would correspond to the resistance on tyson's board

djasper-ha, 2025-01-12:
Not currently, but I'll get some.

djasper-ha, 2025-01-17:
I tried with 4.7k Ohm as R4 and R6, but there wasn't any change in behavior. So, at least for this case it probably still is more of a software issue.

14yannick, 2025-01-18:
Chatgpt suggest following code change for the sync break.
```
/* Start with a Sync Break */
tx_counter = 0;
TX1STAbits.SENDB = 1;   // Enable Break sequence
TX1REG = 0x00;          // Write dummy value to initiate the break

/* Wait for SENDB to clear (Break complete) */
while (TX1STAbits.SENDB);  // Poll until SENDB is cleared by hardware

/* Write Sync Byte (0x55) */
TX1REG = 0x55;          // Sync byte follows the break

/* Enable Transmit Interrupt */
TX1IE = 1;              // Enable transmit interrupt

```
The while part looks interesting it may replace the arbitrary wait 2ms

djasper-ha, 2025-02-04:
I tried waiting for SENDB to clear, but it did not change the behavior. So, this probably needs more debugging.
(It's not high priority for me right now as I do have a working board)

14yannick, 2025-02-04:
I playing around making a Baudrate change in the PIC16 code as it's done in the esp. I will keep you updated as soon I got it working with my Supramatic E3 motor.

sebagsm, 2025-02-10:
hi! I got the tynet board. can someone pls help me how can I start the bus scan on the lineamatic2 ? thanks

sebagsm, 2025-02-10:
nope. so the adapter is needed. thanks for your help :) I will send them and email.

djasper-ha, 2025-02-10:
Yes. If you take a look at the compatibility table in the third comment above: https://github.com/stephan192/hoermann_door/issues/18#issuecomment-1485815572

Lineamatic and Lineamatic 2 both use the older variant of the bus protocol, shared with the Supramatic (E)3. For those, the adapter is necessary and you will also need a different firmware (I ordered mine with the E3 adapter and the E3 firmware pre-flashed).

sebagsm, 2025-02-10:
thanks for your help. this is the firmware in your board: esp32s3_tynet_BME280.bin ?

djasper-ha, 2025-02-10:
No, that's different. If you are interested:
esp32s3 - The s3 here is the flavor of the ESP32 chip (not the Supramatic 3 - yay abbreviations)
BM280 - This is if you want to attach (solder on) a BME280 temperature and humidity sensor.

What you need is the supramatic-e3.ota.bin (or supramatic-e3.factory.bin) from the top-level directory. Note that this is a EspHome based firmware and so you'll need to use that instead of MQTT to interact with the board.

sebagsm, 2025-02-10:
yes, thanks. I just flashed it.. I didnt know there is only esphome fw for supramatic. thanks

Tysonpower, 2025-06-18:
@kovlo i know that it works with lineamatic 2 motors from a customer :)

kovlo, 2025-06-18:
> i know that it works with lineamatic 2 motors from a customer :)

@Tysonpower Great, thank you! I am not sure what is my motor's version, but I will give it a try and I'll report what I find.

Closed 2023-08-29.

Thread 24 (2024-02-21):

BOM?

4920441, 2024-02-21:
Hi,

didn't find a bill of material. Did I miss it or do I have to guess lots of the components?

Thanks a lot!

Cheers

4920441

4920441, 2024-02-21:
Sorry..... if someone is as blind as I am... here is the link:-)

board/RS485Interface_partlist.txt

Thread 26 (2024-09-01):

error 4 after disconnection

ljames8, 2024-09-01:
Hi there, I'm exploring what you guys did with this reverse engineering, it's really great, thank you.
I managed to communicate with my Supramatic E3, and I am now able to open/close my garage door thanks to you.
For now, I followed https://github.com/raintonr/hormann-hcp to connect from my laptop.

However, whenever I close the serial port, or disconnect the RJ12 cable, my radio controller stops working and the drive displays error 4 ("Stop UAP pressed" from the manual).
I see there is a [reference to this issue](https://community.home-assistant.io/t/hormann-garage-door-via-mqtt/279938/26?u=ljames8) which you already answered to. @stephan192  do you know a way to gracefully disconnect the emulated UAP1 device to avoid this error ?
Additional info: after the error 4 shows up, if I reopen the serial port, the radio controller works again.

stephan192, 2024-09-02:
Hi @ljames8, like i already mentioned in the referenced issue i think there is no gracefull way to disconnect. Once you have connected you must stay connected (and respond with messages) forever. **Only option i know: Perform a factory reset.**

This for example is one of the reasons i've design my own PCB. I would never ever use a PC based solution, for something like this.

ljames8, 2024-09-04:
Hi, thanks for the quick reply!

**TL;DR: I think I found a workaround:** simply changing `UAP1_TYPE` to a low value ( tested only with `0x02` and `0x03`) seems to allow the communication errors to be discarded by the master.

**Details**
With  UAP1 type `0x14` I confirm there seems to be no way around either a factory reset or starting to respond again to slave status requests in order to keep the radio controllers working normally.

However for fun I just tried and analyzed the replies the master sends while incrementing `UAP1_TYPE` from `0x00`and on. For this, I setup my client to answer only to slave scan queries, not status requests.
It looks like that:
* from `0x04` until at least `0x2b` types, the behavior is the same as the default `0x14`one.
* But from `0x00` to `0x03` the master sends 6 consecutive requests, then pause until next slave scan if no reply, then start again with 6 requests.

I quickly tested `0x02` and `0x03` types and successfully managed to operate the door from both my client and the radio control, despite my client not replying to status requests or being connected at all.

I'll try to confirm everything works as expected and is stable enough, but if so, it may be safer to change the emulated slave device `UAP1_TYPE` as I did

Semiranis, 2024-10-07:
Did you try other address numbers?

According to Hormann patents, addresses 16-45 are for devices (actuators, safety elements, etc.), so it may be safety reason to stop the operation of whole system (if one element is not working, it's usually better to stop everything, than risk some serious injury or equipment/property damage).

I think you could try address 144 (diagnostic device), or something between 129-143 (for control devices). The patent is not clear, because in ohter place it tells that after 144 it jumps to 142 (omits 143).

Closed 2025-01-13.

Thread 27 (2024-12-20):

Supported devices

halacs, 2024-12-20:
Hi,

I have a ProMatic 3 door opener motor. Is it supported by this solution?

Thanks!

stephan192, 2024-12-20:
I'm not sure but according to https://github.com/stephan192/hoermann_door/issues/18#issuecomment-1485815572 i would guess NO.
Your door must be compatible with the "UAP 1" because my board emulates a "UAP 1".

14yannick, 2024-12-28:
Hi @stephan192 is right it's not compatible. I have a section in the [Document](https://docs.google.com/document/d/17D7XYupXnDYqXbOIze-K6jELF5pCdjmzDuHnc6SLtuA/edit?usp=drivesdk)  how you can have the functionality using a relay and reed sensors.

4920441, 2025-02-22:
Hi,

Hörmann hast at least two different systems it seems.... My Supramatic 4 needs the uap-1-HCP version:-(

https://www.tor7.de/hoermann-universaladapterplatine-uap-1-hcp

Is your project able to use that one too, somehow?

Why do they invent the wheel over and over again..... a garage door should be a very finite machine....

Cheers

14yannick, 2025-02-22:
Check [this](https://github.com/14yannick/esphome-hcpbridge) repo for uap-hcp. This need much easier hardware. You can get preassembled boards from tysonpower or I can also assist you.

4920441, 2025-02-23:
Hi,  thanks for that hint.

If someone iss interested in the board I've purchased, please let me now - its sits here as it was delivered.

I think there is no reason to modify it, when most of the components are not needed for my version, or is there?

Thaanks   a lot for clearyfying - really thought I hat a supramatic 3 in my garage......;-)

Cheers

Closed 2025-06-01.

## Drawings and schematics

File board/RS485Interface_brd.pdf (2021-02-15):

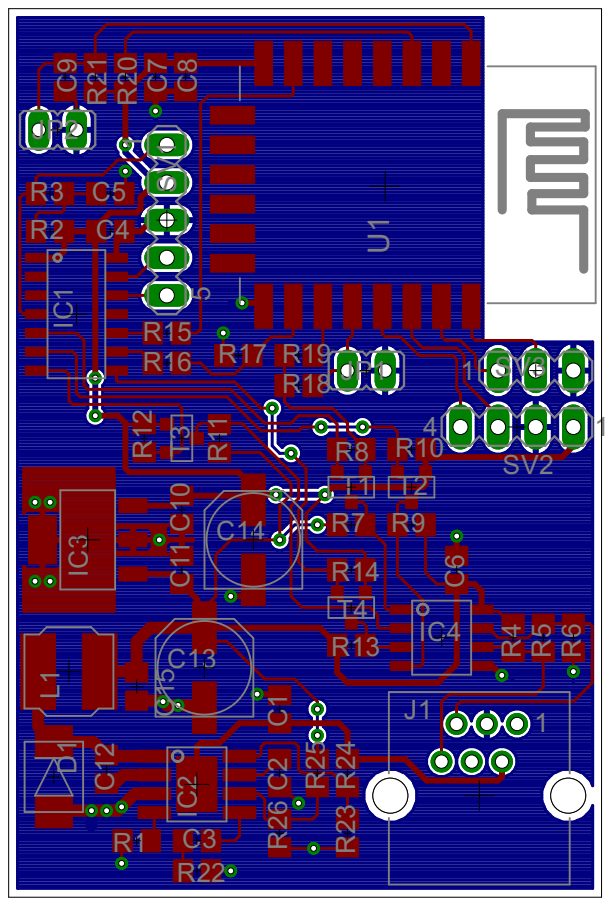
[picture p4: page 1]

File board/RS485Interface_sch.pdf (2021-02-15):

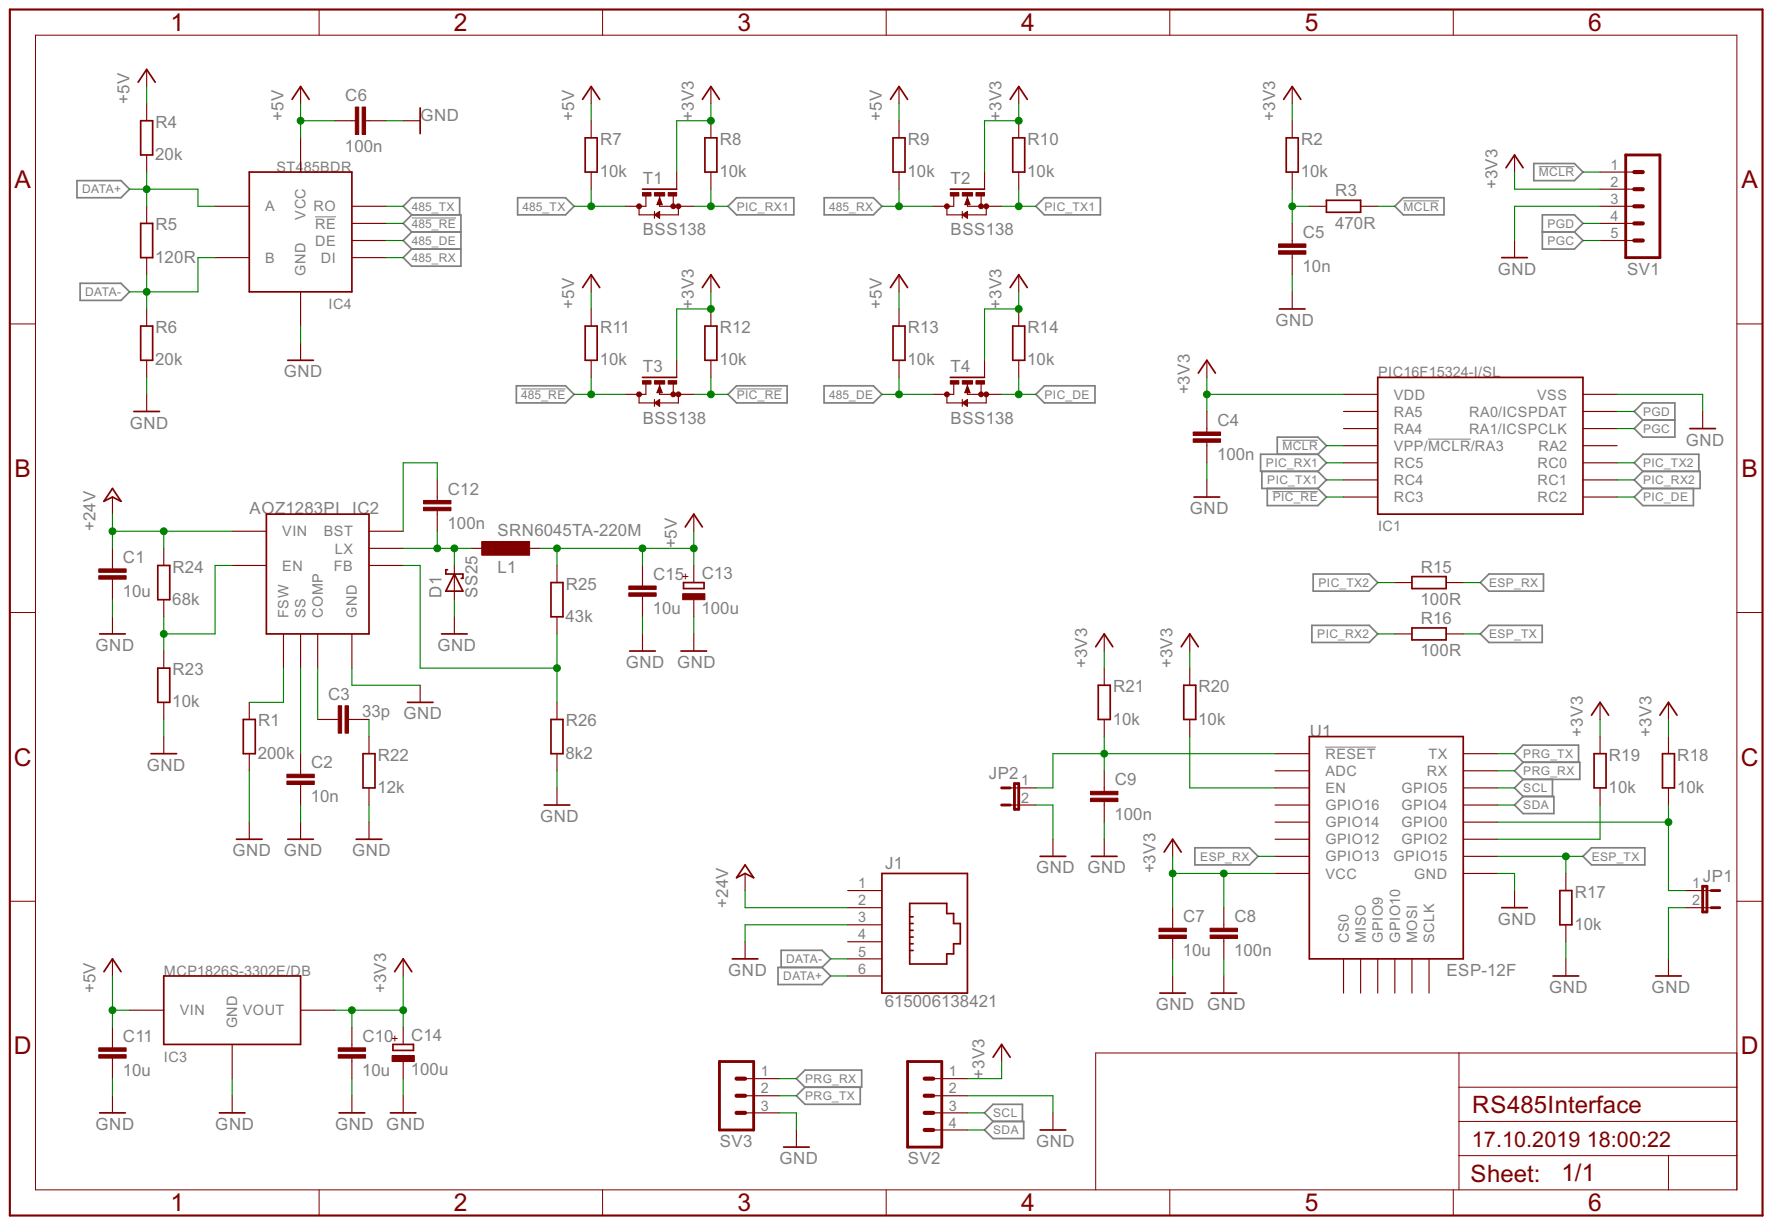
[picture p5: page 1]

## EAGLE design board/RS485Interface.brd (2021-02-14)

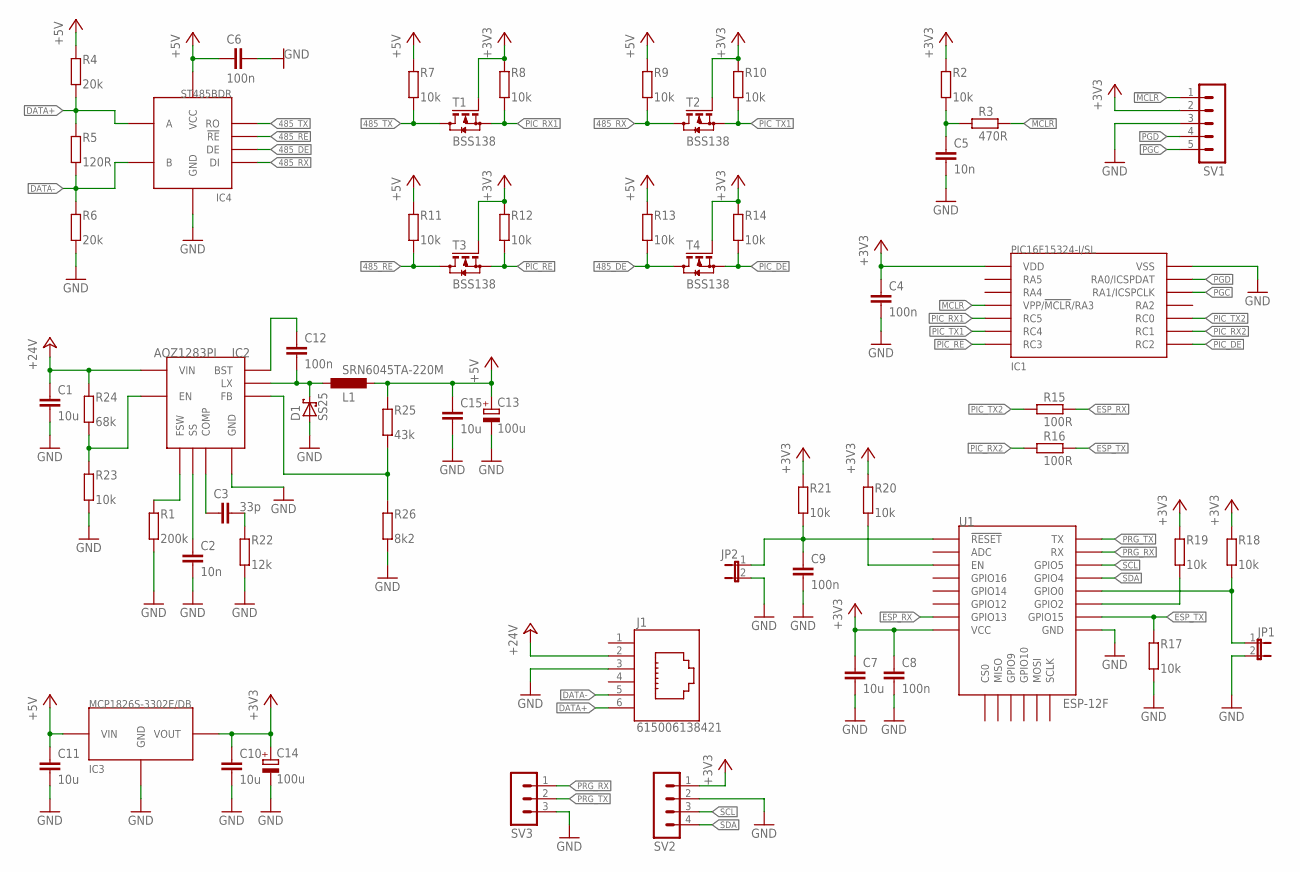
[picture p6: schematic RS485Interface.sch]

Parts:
C1, C7, C10, C11, C15: 10u; C0805
C2, C5: 10n; C0805
C3: 33p; C0805
C4, C6, C8, C9, C12: 100n; C0805
C13, C14: 100u; UCL6.3
D1: SS25; DO-214AA
IC1: PIC16F15324-I/SL; SOIC14
IC2: AOZ1283PI; SO8+PAD
IC3: MCP1826S-3302E/DB; SOT-223-3
IC4: ST485BDR; SOIC8
J1: 615006138421
JP1, JP2: JP1E; JP1
L1: SRN6045TA-220M; SRN6045TA
R1: 200k; R0805
R2, R7, R8, R9, R10, R11, R12, R13, R14, R17, R18, R19, R20, R21, R23: 10k; R0805
R3: 470R; R0805
R4, R6: 20k; R0805
R5: 120R; R0805
R15, R16: 100R; R0805
R22: 12k; R0805
R24: 68k; R0805
R25: 43k; R0805
R26: 8k2; R0805
SV1: MA05-1
SV2: MA04-1
SV3: MA03-1
T1, T2, T3, T4: BSS138; SOT-23
U1: ESP-12F; ESP12E-SMD

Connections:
485_DE: IC4.P3 (DE), R13.1, T4.P3 (D)
485_RX: IC4.P4 (DI), R9.1, T2.P3 (D)
485_TX: IC4.P1 (RO), R7.1, T1.P3 (D)
!485_RE: IC4.P2 (!RE), R11.1, T3.P3 (D)
!MCLR: IC1.P4 (VPP/!MCLR!/RA3), R3.1, SV1.1
!PIC_RE: IC1.P7 (RC3), R12.1, T3.P2 (S)
!RESET: C9.1, JP2.1, R21.1, U1.RESET (!RESET)
+3V3: C4.1, C7.1, C8.1, C10.1, C14.+, IC1.P1 (VDD), IC3.P3 (VOUT), R2.2, R8.2, R10.2, R12.2, R14.2, R18.2, R19.2, R20.2, R21.2, SV1.2, SV2.1, T1.P1 (G), T2.P1 (G), T3.P1 (G), T4.P1 (G), U1.VCC
+5V: C6.1, C11.1, C13.+, C15.1, IC3.P1 (VIN), IC4.P8 (VCC), L1.P$1 (1), R4.2, R7.2, R9.2, R11.2, R13.2, R25.2
+24V: C1.1, IC2.PAD (VIN), J1.2 (5), R24.2
DATA+: IC4.P6 (A), J1.6 (1), R4.1, R5.2
DATA-: IC4.P7 (B), J1.5 (2), R5.1, R6.2
EN: R20.1, U1.EN
ESP_RX: R15.1, U1.GPIO13
ESP_TX: R16.1, R17.2, U1.GPIO15
GND: C1.2, C2.2, C4.2, C5.2, C6.2, C7.2, C8.2, C9.2, C10.2, C11.2, C13.-, C14.-, C15.2, D1.A, IC1.P14 (VSS), IC2.P3 (GND), IC3.P2 (GND), IC3.P4 (GND), IC4.P5 (GND), J1.3 (4), JP1.2, JP2.2, R1.1, R6.1, R17.1, R22.1, R23.1, R26.1, SV1.3, SV2.2, SV3.3, U1.GND
GPIO0: JP1.1, R18.1, U1.GPIO0
GPIO2: R19.1, U1.GPIO2
LX: C12.2, D1.C, IC2.P1 (LX), L1.P$2 (2)
unnamed: IC2.P8 (EN), R23.2, R24.1
unnamed: C3.1, IC2.P5 (COMP)
unnamed: C5.1, R2.1, R3.2
unnamed: C3.2, R22.2
unnamed: C2.1, IC2.P7 (SS)
unnamed: IC2.P4 (FSW), R1.2
unnamed: IC2.P6 (FB), R25.1, R26.2
unnamed: C12.1, IC2.P2 (BST)
PGC: IC1.P12 (RA1/ICSPCLK), SV1.5
PGD: IC1.P13 (RA0/ICSPDAT), SV1.4
PIC_DE: IC1.P8 (RC2), R14.1, T4.P2 (S)
PIC_RX1: IC1.P5 (RC5), R8.1, T1.P2 (S)
PIC_RX2: IC1.P9 (RC1), R16.2
PIC_TX1: IC1.P6 (RC4), R10.1, T2.P2 (S)
PIC_TX2: IC1.P10 (RC0), R15.2
PRG_RX: SV3.1, U1.RXD0 (RX)
PRG_TX: SV3.2, U1.TXD0 (TX)
SCL: SV2.3, U1.GPIO5
SDA: SV2.4, U1.GPIO4

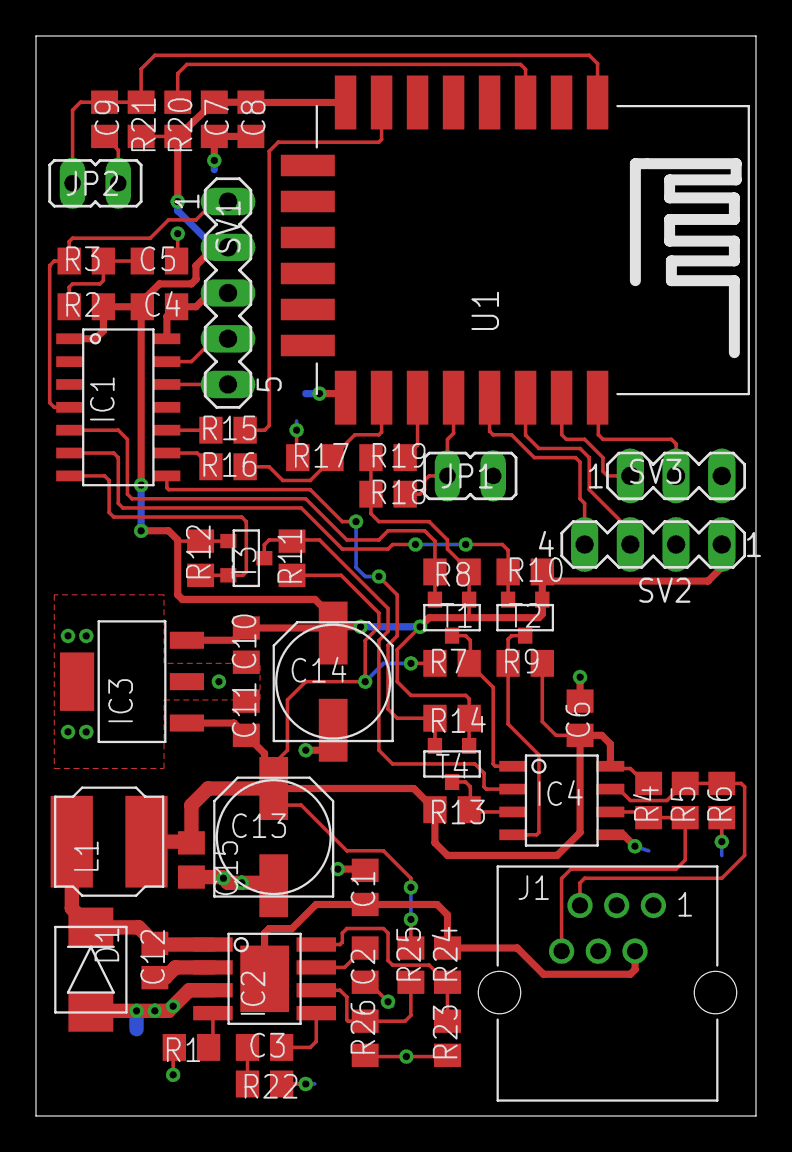
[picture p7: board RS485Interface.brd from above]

Board: 2 copper layers, 40.0 x 60.0 mm, 58 parts (0 on the bottom side), 38 nets.

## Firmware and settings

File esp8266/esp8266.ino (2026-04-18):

#include "config.h"
#include <ESP8266WiFi.h>
#include <ArduinoOTA.h>
#include <PubSubClient.h>
#include <PubSubClientTools.h>
#include <Adafruit_Sensor.h>
#include <Adafruit_BME280.h>
#include "hoermann.h"

#define HW_VERSION "v1"
#define SW_VERSION "v3.2"

WiFiClient espClient;
PubSubClient client(MQTT_SERVER, MQTT_PORT, espClient);
PubSubClientTools mqtt(client);
String unique_id;

Hoermann door;
hoermann_state_t current_door_state;
hoermann_state_t last_door_state;

Adafruit_BME280 bme; // I2C
bool bme_detected = false;
uint32_t ReconnectCounter = 0;
uint32_t StartTime;

String cover_avty_topic;
String cover_cmd_topic;
String cover_pos_topic;
String venting_cmd_topic;
String venting_state_topic;
String light_cmd_topic;
String light_state_topic;
String error_state_topic;
String prewarn_state_topic;
String option_relay_state_topic;
String emergency_stop_cmd_topic;
String impulse_cmd_topic;
String bme_avty_topic;
String bme_state_topic;

void setup() {
  last_door_state.data_valid = false;

  Serial.begin(115200);
  Serial.println();

  // Connect to WiFi
  Serial.print("Connecting to WiFi: ");
  Serial.print(WIFI_SSID);
  WiFi.mode(WIFI_STA);
  WiFi.hostname(HOSTNAME);
  WiFi.begin(WIFI_SSID, WIFI_PASS);
  while (WiFi.status() != WL_CONNECTED) {
    delay(500);
    Serial.print(".");
  }
  Serial.println("connected");

  // Port defaults to 8266
  // ArduinoOTA.setPort(8266);

  // Hostname defaults to esp8266-[ChipID]
  ArduinoOTA.setHostname(HOSTNAME);

  // No authentication by default
  ArduinoOTA.setPassword(OTA_PASSWORT);

  ArduinoOTA.onStart([]() {
    String type;
    if (ArduinoOTA.getCommand() == U_FLASH) {
      type = "sketch";
    } else { // U_SPIFFS
      type = "filesystem";
    }

    // NOTE: if updating SPIFFS this would be the place to unmount SPIFFS using SPIFFS.end()
    Serial.println("Start updating " + type);
  });
  ArduinoOTA.onEnd([]() {
    Serial.println("\nEnd");
  });
  ArduinoOTA.onProgress([](unsigned int progress, unsigned int total) {
    Serial.printf("Progress: %u%%\r", (progress / (total / 100)));
  });
  ArduinoOTA.onError([](ota_error_t error) {
    Serial.printf("Error[%u]: ", error);
    if (error == OTA_AUTH_ERROR) {
      Serial.println("Auth Failed");
    } else if (error == OTA_BEGIN_ERROR) {
      Serial.println("Begin Failed");
    } else if (error == OTA_CONNECT_ERROR) {
      Serial.println("Connect Failed");
    } else if (error == OTA_RECEIVE_ERROR) {
      Serial.println("Receive Failed");
    } else if (error == OTA_END_ERROR) {
      Serial.println("End Failed");
    }
  });
  ArduinoOTA.begin();
  Serial.print("OTA ready - IP address: ");
  Serial.println(WiFi.localIP());

  // Connect BME sensor
  bme_detected = bme.begin(BME280_I2C_ADR);
  if (bme_detected)
  {
    Serial.println("BME connected!");
  }
  else
  {
    Serial.println("BME not found!");
  }

  // Connect to MQTT
  byte mac[6];
  WiFi.macAddress(mac);
  unique_id = "hoermann_door_" + String(mac[0], HEX) + String(mac[1], HEX) + String(mac[2], HEX) + String(mac[3], HEX) + String(mac[4], HEX) + String(mac[5], HEX);
  unique_id.toLowerCase();
  Serial.print("MQTT client id: ");
  Serial.println(unique_id);
  setup_mqtt_topics();

  Serial.print("Connecting to MQTT: ");
  Serial.print(MQTT_SERVER);
  Serial.print("...");
  if (connect_mqtt()) {
    Serial.println("connected");
    publish_mqtt_autodiscovery();
    mqtt_init_publish_and_subscribe();
  } else {
    Serial.print("failed, rc=");
    Serial.println(client.state());
  }

  // Configure serial interface for door communication
  Serial.flush();
  Serial.end();
  Serial.begin(19200);
  Serial.swap();

  StartTime = millis();
}

void loop()
{
  door.loop();

  if (WiFi.status() != WL_CONNECTED)
  {
    reconnect_wifi();
    ReconnectCounter++;
    last_door_state.data_valid = false;
  }
  else
  {
    if (!client.connected()) {
      reconnect_mqtt();
      ReconnectCounter++;
      last_door_state.data_valid = false;
    }
    else
    {
      client.loop();

      process_door_data();

      if (bme_detected)
      {
        read_bme();
      }
      else
      {
        connect_bme();
      }

      if (ReconnectCounter > 0) {
        ReconnectCounter--;
      }
    }

    ArduinoOTA.handle();
  }

  if (ReconnectCounter > 100) {
    ESP.restart();
  }
}

void reconnect_wifi() {
  WiFi.disconnect();
  WiFi.mode(WIFI_OFF);
  WiFi.mode(WIFI_STA);
  WiFi.begin(WIFI_SSID, WIFI_PASS);
  delay(500);
}

void reconnect_mqtt() {

  if (connect_mqtt()) {
    mqtt_init_publish_and_subscribe();
  } else {
    delay(500);
  }
}

bool connect_mqtt() {
  if (client.connect(unique_id.c_str(), MQTT_USER, MQTT_PASSWORD, cover_avty_topic.c_str(), 0, true, "offline")) {
    // Run loop a few times before proceeding
    for (int i = 0; i < 50; i++) {
      client.loop();
      delay(10);
    }
    return client.connected();
  }
  else
  {
    return false;
  }
}

void read_bme(void)
{
  String message;
  uint32_t CurrentTime;

  CurrentTime = millis();
  if ((CurrentTime - StartTime) >= 30000)
  {
    StartTime = CurrentTime;

    Wire.beginTransmission(BME280_I2C_ADR);
    if (Wire.endTransmission() == 0)
    {
      message = "{ \"temperature_C\" : " + String(bme.readTemperature()) + ", \"humidity\" : " + String(bme.readHumidity()) + ", \"pressure_hPa\" : " + String(bme.readPressure() / 100.0F) + " }";
      mqtt.publish(bme_state_topic, message, true);
    }
    else
    {
      mqtt.publish(bme_avty_topic, "offline", true);
      bme_detected = false;
    }
  }
}

void connect_bme(void)
{
  String message;
  uint32_t CurrentTime;

  CurrentTime = millis();
  if ((CurrentTime - StartTime) >= 30000)
  {
    StartTime = CurrentTime;

    bme_detected = bme.begin(BME280_I2C_ADR);
    if (bme_detected)
    {
      mqtt.publish(bme_avty_topic, "online", true);
    }
  }
}

void process_door_data() {
  current_door_state = door.get_state();
  /* Terminate if data is not valid */
  if (!current_door_state.data_valid)
  {
    return;
  }

  if ((current_door_state.cover != last_door_state.cover) || (!last_door_state.data_valid))
  {
    String position_message;
    switch (current_door_state.cover)
    {
      case cover_open:
        position_message = "100";
        break;
      case cover_closed:
        position_message = "0";
        break;
      default:
        position_message = "10";
        break;
    }
    mqtt.publish(cover_pos_topic, position_message, true);
    last_door_state.cover = current_door_state.cover;
  }
  if ((current_door_state.venting != last_door_state.venting) || (!last_door_state.data_valid))
  {
    String state_message;
    if (current_door_state.venting)
    {
      state_message = "ON";
    }
    else
    {
      state_message = "OFF";
    }
    mqtt.publish(venting_state_topic, state_message, true);
    last_door_state.venting = current_door_state.venting;
  }
  if ((current_door_state.light != last_door_state.light) || (!last_door_state.data_valid))
  {
    String state_message;
    if (current_door_state.light)
    {
      state_message = "ON";
    }
    else
    {
      state_message = "OFF";
    }
    mqtt.publish(light_state_topic, state_message, true);
    last_door_state.light = current_door_state.light;
  }
  if ((current_door_state.error != last_door_state.error) || (!last_door_state.data_valid))
  {
    String state_message;
    if (current_door_state.error)
    {
      state_message = "ON";
    }
    else
    {
      state_message = "OFF";
    }
    mqtt.publish(error_state_topic, state_message, true);
    last_door_state.error = current_door_state.error;
  }
  if ((current_door_state.prewarn != last_door_state.prewarn) || (!last_door_state.data_valid))
  {
    String state_message;
    if (current_door_state.prewarn)
    {
      state_message = "ON";
    }
    else
    {
      state_message = "OFF";
    }
    mqtt.publish(prewarn_state_topic, state_message, true);
    last_door_state.prewarn = current_door_state.prewarn;
  }
  if ((current_door_state.option_relay != last_door_state.option_relay) || (!last_door_state.data_valid))
  {
    String state_message;
    if (current_door_state.option_relay)
    {
      state_message = "ON";
    }
    else
    {
      state_message = "OFF";
    }
    mqtt.publish(option_relay_state_topic, state_message, true);
    last_door_state.option_relay = current_door_state.option_relay;
  }
  last_door_state.data_valid = current_door_state.data_valid;
}

void setup_mqtt_topics() {
  cover_avty_topic = "homeassistant/cover/" + unique_id + "_cover/availability";
  cover_cmd_topic = "homeassistant/cover/" + unique_id + "_cover/command";
  cover_pos_topic = "homeassistant/cover/" + unique_id + "_cover/position";

  venting_cmd_topic = "homeassistant/switch/" + unique_id + "_venting/command";
  venting_state_topic = "homeassistant/switch/" + unique_id + "_venting/state";

  light_cmd_topic = "homeassistant/switch/" + unique_id + "_light/command";
  light_state_topic = "homeassistant/switch/" + unique_id + "_light/state";

  error_state_topic = "homeassistant/binary_sensor/" + unique_id + "_error/state";
  prewarn_state_topic = "homeassistant/binary_sensor/" + unique_id + "_prewarn/state";
  option_relay_state_topic = "homeassistant/binary_sensor/" + unique_id + "_option_relay/state";

  emergency_stop_cmd_topic = "homeassistant/button/" + unique_id + "_emergency_stop/trigger";
  impulse_cmd_topic = "homeassistant/button/" + unique_id + "_impulse/trigger";

  bme_avty_topic = "homeassistant/sensor/" + unique_id + "_bme/availability";
  bme_state_topic = "homeassistant/sensor/" + unique_id + "_bme/state";
}

void mqtt_init_publish_and_subscribe() {
  mqtt.subscribe(cover_cmd_topic, cover_cmd_subscriber);
  mqtt.subscribe(venting_cmd_topic, venting_cmd_subscriber);
  mqtt.subscribe(light_cmd_topic, light_cmd_subscriber);
  mqtt.subscribe(emergency_stop_cmd_topic, emergency_stop_cmd_subscriber);
  mqtt.subscribe(impulse_cmd_topic, impulse_cmd_subscriber);

  mqtt.publish(cover_avty_topic, "online", true);
  if (bme_detected)
  {
    mqtt.publish(bme_avty_topic, "online", true);
  }
  else
  {
    mqtt.publish(bme_avty_topic, "offline", true);
  }
}

void publish_mqtt_autodiscovery() {
  String topic;
  String payload;

  String device = "\"dev\":{\"ids\":\"" + unique_id + "\", \"name\":\"" + HOSTNAME + "\", \"mdl\":\"Hoermann Door\", \"mf\":\"stephan192\", \"hw\":\"" + String(HW_VERSION) + "\", \"sw\":\"" + String(SW_VERSION) + "\"}";
  String obj_id = String(HOSTNAME);
  obj_id.toLowerCase();

  topic = "homeassistant/cover/" + unique_id + "_cover/config";
  payload = "{\"~\":\"homeassistant/cover/" + unique_id + "_cover\", \"avty_t\":\"~/availability\", \"cmd_t\":\"~/command\", " + device + ", \"dev_cla\":\"garage\", \"name\":\"Garage door\", \"def_ent_id\":\"cover." + obj_id + "_cover\", \"pos_t\":\"~/position\", \"uniq_id\":\"" + unique_id + "_cover\", \"en\":\"true\"}";
  publish_oversize_payload(topic, payload, true);

  topic = "homeassistant/switch/" + unique_id + "_venting/config";
  payload = "{\"~\":\"homeassistant/switch/" + unique_id + "_venting\", \"avty_t\":\"" + cover_avty_topic + "\", \"cmd_t\":\"~/command\", " + device + ", \"icon\":\"mdi:fan\", \"name\":\"Venting\", \"def_ent_id\":\"switch." + obj_id + "_venting\", \"stat_t\":\"~/state\", \"uniq_id\":\"" + unique_id + "_venting\", \"en\":\"true\"}";
  publish_oversize_payload(topic, payload, true);

  topic = "homeassistant/switch/" + unique_id + "_light/config";
  payload = "{\"~\":\"homeassistant/switch/" + unique_id + "_light\", \"avty_t\":\"" + cover_avty_topic + "\", \"cmd_t\":\"~/command\", " + device + ", \"icon\":\"mdi:lightbulb\", \"name\":\"Light\", \"def_ent_id\":\"switch." + obj_id + "_light\", \"stat_t\":\"~/state\", \"uniq_id\":\"" + unique_id + "_light\", \"en\":\"false\"}";
  publish_oversize_payload(topic, payload, true);

  topic = "homeassistant/binary_sensor/" + unique_id + "_error/config";
  payload = "{\"~\":\"homeassistant/binary_sensor/" + unique_id + "_error\", \"avty_t\":\"" + cover_avty_topic + "\", " + device + ", \"dev_cla\":\"problem\", \"name\":\"Error\", \"def_ent_id\":\"binary_sensor." + obj_id + "_error\", \"stat_t\":\"~/state\", \"uniq_id\":\"" + unique_id + "_error\", \"en\":\"true\"}";
  publish_oversize_payload(topic, payload, true);

  topic = "homeassistant/binary_sensor/" + unique_id + "_prewarn/config";
  payload = "{\"~\":\"homeassistant/binary_sensor/" + unique_id + "_prewarn\", \"avty_t\":\"" + cover_avty_topic + "\", " + device + ", \"dev_cla\":\"safety\", \"name\":\"Prewarn\", \"def_ent_id\":\"binary_sensor." + obj_id + "_prewarn\", \"stat_t\":\"~/state\", \"uniq_id\":\"" + unique_id + "_prewarn\", \"en\":\"false\"}";
  publish_oversize_payload(topic, payload, true);

  topic = "homeassistant/binary_sensor/" + unique_id + "_option_relay/config";
  payload = "{\"~\":\"homeassistant/binary_sensor/" + unique_id + "_option_relay\", \"avty_t\":\"" + cover_avty_topic + "\", " + device + ", \"name\":\"Option relay\", \"def_ent_id\":\"binary_sensor." + obj_id + "_option_relay\", \"stat_t\":\"~/state\", \"uniq_id\":\"" + unique_id + "_option_relay\", \"en\":\"false\"}";
  publish_oversize_payload(topic, payload, true);

  topic = "homeassistant/button/" + unique_id + "_emergency_stop/config";
  payload = "{\"~\":\"homeassistant/button/" + unique_id + "_emergency_stop\", \"avty_t\":\"" + cover_avty_topic + "\", \"cmd_t\":\"homeassistant/button/" + unique_id + "_emergency_stop/trigger\", " + device + ", \"icon\":\"mdi:close-octagon\", \"name\":\"Emergency stop\", \"def_ent_id\":\"button." + obj_id + "_emergency_stop\", \"uniq_id\":\"" + unique_id + "_emergency_stop\", \"en\":\"false\"}";
  publish_oversize_payload(topic, payload, true);

  topic = "homeassistant/button/" + unique_id + "_impulse/config";
  payload = "{\"~\":\"homeassistant/button/" + unique_id + "_impulse\", \"avty_t\":\"" + cover_avty_topic + "\", \"cmd_t\":\"homeassistant/button/" + unique_id + "_impulse/trigger\", " + device + ", \"icon\":\"mdi:arrow-up-down\", \"name\":\"Impulse\", \"def_ent_id\":\"button." + obj_id + "_impulse\", \"uniq_id\":\"" + unique_id + "_impulse\", \"en\":\"false\"}";
  publish_oversize_payload(topic, payload, true);

  topic = "homeassistant/sensor/" + unique_id + "_temperature/config";
  payload = "{\"avty\":[{\"topic\":\"" + cover_avty_topic + "\"}, {\"topic\":\"" + bme_avty_topic + "\"}], \"avty_mode\":\"all\", " + device + ", \"dev_cla\":\"temperature\", \"name\":\"Temperature\", \"def_ent_id\":\"sensor." + obj_id + "_temperature\", \"stat_cla\":\"measurement\", \"stat_t\":\"" + bme_state_topic + "\", \"uniq_id\":\"" + unique_id + "_temperature\", \"unit_of_meas\":\"\u00b0C\", \"val_tpl\":\"{{value_json.temperature_C|round(1)}}\", \"en\":\"true\"}";
  publish_oversize_payload(topic, payload, true);

  topic = "homeassistant/sensor/" + unique_id + "_humidity/config";
  payload = "{\"avty\":[{\"topic\":\"" + cover_avty_topic + "\"}, {\"topic\":\"" + bme_avty_topic + "\"}], \"avty_mode\":\"all\", " + device + ", \"dev_cla\":\"humidity\", \"name\":\"Humidity\", \"def_ent_id\":\"sensor." + obj_id + "_humidity\", \"stat_cla\":\"measurement\", \"stat_t\":\"" + bme_state_topic + "\", \"uniq_id\":\"" + unique_id + "_humidity\", \"unit_of_meas\":\"%\", \"val_tpl\":\"{{value_json.humidity|round(0)}}\", \"en\":\"true\"}";
  publish_oversize_payload(topic, payload, true);

  topic = "homeassistant/sensor/" + unique_id + "_pressure/config";
  payload = "{\"avty\":[{\"topic\":\"" + cover_avty_topic + "\"}, {\"topic\":\"" + bme_avty_topic + "\"}], \"avty_mode\":\"all\", " + device + ", \"dev_cla\":\"pressure\", \"name\":\"Pressure\", \"def_ent_id\":\"sensor." + obj_id + "_pressure\", \"stat_cla\":\"measurement\", \"stat_t\":\"" + bme_state_topic + "\", \"uniq_id\":\"" + unique_id + "_pressure\", \"unit_of_meas\":\"hPa\", \"val_tpl\":\"{{value_json.pressure_hPa|round(1)}}\", \"en\":\"true\"}";
  publish_oversize_payload(topic, payload, true);

  Serial.println("MQTT autodiscovery sent");
}

void publish_oversize_payload(String topic, String payload, bool retain)
{
  String substr;
  unsigned int index = 0u;
  unsigned int payload_len = payload.length();
  unsigned int count;

  client.beginPublish(topic.c_str(), payload.length(), retain);
  while (index < payload_len)
  {
    count = payload_len - index;
    if (count > MQTT_MAX_PACKET_SIZE) count = MQTT_MAX_PACKET_SIZE;

    substr = payload.substring(index, (index + count));
    client.write((byte*)substr.c_str(), count);
    index += count;
  }
  client.endPublish();
}

void cover_cmd_subscriber(String topic, String message)
{
  if (message == "OPEN")
  {
    door.trigger_action(hoermann_action_open);
  }
  else if (message == "CLOSE")
  {
    door.trigger_action(hoermann_action_close);
  }
  else if (message == "STOP")
  {
    door.trigger_action(hoermann_action_stop);
  }
}

void venting_cmd_subscriber(String topic, String message)
{
  if (message == "ON")
  {
    door.trigger_action(hoermann_action_venting);
  }
  else if (message == "OFF")
  {
    door.trigger_action(hoermann_action_close);
  }
}

void light_cmd_subscriber(String topic, String message)
{
  if ((message == "ON") || (message == "OFF"))
  {
    door.trigger_action(hoermann_action_toggle_light);
  }
}

void emergency_stop_cmd_subscriber(String topic, String message)
{
  if (message == "PRESS")
  {
    door.trigger_action(hoermann_action_emergency_stop);
  }
}

void impulse_cmd_subscriber(String topic, String message)
{
  if (message == "PRESS")
  {
    door.trigger_action(hoermann_action_impulse);
  }
}

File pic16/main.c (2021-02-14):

// CONFIG1
#pragma config FEXTOSC = OFF    // External Oscillator mode selection bits (Oscillator not enabled)
#pragma config RSTOSC = HFINT32 // Power-up default value for COSC bits (HFINTOSC with OSCFRQ= 32 MHz and CDIV = 1:1)
#pragma config CLKOUTEN = OFF   // Clock Out Enable bit (CLKOUT function is disabled; i/o or oscillator function on OSC2)
#pragma config CSWEN = ON       // Clock Switch Enable bit (Writing to NOSC and NDIV is allowed)
#pragma config FCMEN = ON       // Fail-Safe Clock Monitor Enable bit (FSCM timer enabled)

// CONFIG2
#pragma config MCLRE = ON       // Master Clear Enable bit (MCLR pin is Master Clear function)
#pragma config PWRTE = OFF      // Power-up Timer Enable bit (PWRT disabled)
#pragma config LPBOREN = OFF    // Low-Power BOR enable bit (ULPBOR disabled)
#pragma config BOREN = ON       // Brown-out reset enable bits (Brown-out Reset Enabled, SBOREN bit is ignored)
#pragma config BORV = LO        // Brown-out Reset Voltage Selection (Brown-out Reset Voltage (VBOR) set to 1.9V on LF, and 2.45V on F Devices)
#pragma config ZCD = OFF        // Zero-cross detect disable (Zero-cross detect circuit is disabled at POR.)
#pragma config PPS1WAY = ON     // Peripheral Pin Select one-way control (The PPSLOCK bit can be cleared and set only once in software)
#pragma config STVREN = ON      // Stack Overflow/Underflow Reset Enable bit (Stack Overflow or Underflow will cause a reset)

// CONFIG3
#pragma config WDTCPS = WDTCPS_10// WDT Period Select bits (Divider ratio 1:32768)
#pragma config WDTE = ON        // WDT operating mode (WDT enabled regardless of sleep; SWDTEN ignored)
#pragma config WDTCWS = WDTCWS_6// WDT Window Select bits (window always open (100%); no software control; keyed access required)
#pragma config WDTCCS = LFINTOSC// WDT input clock selector (WDT reference clock is the 31.0kHz LFINTOSC output)

// CONFIG4
#pragma config BBSIZE = BB512   // Boot Block Size Selection bits (512 words boot block size)
#pragma config BBEN = OFF       // Boot Block Enable bit (Boot Block disabled)
#pragma config SAFEN = OFF      // SAF Enable bit (SAF disabled)
#pragma config WRTAPP = OFF     // Application Block Write Protection bit (Application Block not write protected)
#pragma config WRTB = OFF       // Boot Block Write Protection bit (Boot Block not write protected)
#pragma config WRTC = OFF       // Configuration Register Write Protection bit (Configuration Register not write protected)
#pragma config WRTSAF = OFF     // Storage Area Flash Write Protection bit (SAF not write protected)
#pragma config LVP = ON         // Low Voltage Programming Enable bit (Low Voltage programming enabled. MCLR/Vpp pin function is MCLR.)

// CONFIG5
#pragma config CP = OFF         // UserNVM Program memory code protection bit (UserNVM code protection disabled)

// #pragma config statements should precede project file includes.
// Use project enums instead of #define for ON and OFF.

#include <xc.h>
#include <stdint.h>
#include <stdbool.h>
#include "sysconfig.h"
#include "hoermann.h"
#include "esp_interface.h"


static void pins_init(void)
{
  LATA   = 0b00000000;
  TRISA  = 0b00001000;
  ANSELA = 0b00000000;
  /*           |||||'-- RA0 - PGD */
  /*           ||||'--- RA1 - PGC */
  /*           |||'---- RA2 - not used */
  /*           ||'----- RA3 - !MCLR */
  /*           |'------ RA4 - not used */
  /*           '------- RA5 - not used */

  LATC   = 0b00010001;
  TRISC  = 0b00100010;
  ANSELC = 0b00000000;
  /*           |||||'-- RC0 - PIC_TX2 */
  /*           ||||'--- RC1 - PIC_RX2 */
  /*           |||'---- RC2 - PIC_DE */
  /*           ||'----- RC3 - !PIC_RE */
  /*           |'------ RC4 - PIC_TX1 */
  /*           '------- RC5 - PIC_RX2 */

  /* RS485-Interface */
  RC4PPS = 0x0F;      /* RC4 - Uart 1 Tx */
  RX1DTPPS = 0b10101; /* RC5 - Uart 1 Rx */
  
  /* ESP-Interface */
  RC0PPS = 0x11;      /* RC0 - Uart 2 Tx */
  RX2DTPPS = 0b10001; /* RC1 - Uart 2 Tx */
}

static void timer_init(void)
{
  /* Caution: Errata 5.1 
   * Operation of Timer0 is Incorrect when FOSC/4 is Used as the Clock Source
   * Clearing the T0ASYNC bit in the T0CON1 register when Timer0 is configured
   * to use FOSC/4 may cause incorrect behavior. This issue is only valid when
   * FOSC/4 is used as the clock source.
   * Work around: Set the T0ASYNC bit in the T0CON1 register when using FOSC/4
   * as the Timer0 clock. */
  
  TMR0L = 0;
  TMR0H = ((uint8_t)((1e-3 * FCY)/256))-1;
  T0CON1 = 0b01111000;
  /*         ||||''''-- T0CKPS - Prescaler Rate Select bit 1:256 */
  /*         |||'------ T0ASYNC - The input to the TMR0 counter is not synchronized to system clocks */
  /*         '''------- T0CS - Timer0 Clock Source select bits HFINTOSC */
  T0CON0 = 0b10000000;
  /*         | ||''''-- T0OUTPS - Timer0 output postscaler (divider) select bits 1:1 */
  /*         | |'------ T016BIT - Timer0 is an 8-bit timer */
  /*         | '------- T0OUT - Timer0 Output bit (read-only) */
  /*         '--------- T0EN - The module is enabled and operating */
}

int main(void)
{
  pins_init();
  timer_init();
  hoermann_init();
  esp_interface_init();
  
   /* Enable interrupts */
  PEIE = 1;
  GIE = 1;
  
  while(1)
  {
    if(TMR0IF == 1)
    {
      /* 1ms Task */
      TMR0IF = 0;
      CLRWDT();
      hoermann_run();
      esp_interface_run();
    }
  }
  
  return 0;
}

void __interrupt() isr(void)
{
  if(RC1IF == 1)
  {
    hoermann_rx_isr();
  }
  if(TX1IF == 1)
  {
    hoermann_tx_isr();
  }
  if(RC2IF == 1)
  {
    esp_rx_isr();
  }
  if(TX2IF == 1)
  {
    esp_tx_isr();
  }
}

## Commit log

2021-02-14 Sources added
    [RS485Interface.brd, RS485Interface.sch]
2021-02-15 Add device_class to configuration.yaml
2021-03-17 Add gerber files
2025-01-03 Use impulse command to stop motor instead of emergency stop command

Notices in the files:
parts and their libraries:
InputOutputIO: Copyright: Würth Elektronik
